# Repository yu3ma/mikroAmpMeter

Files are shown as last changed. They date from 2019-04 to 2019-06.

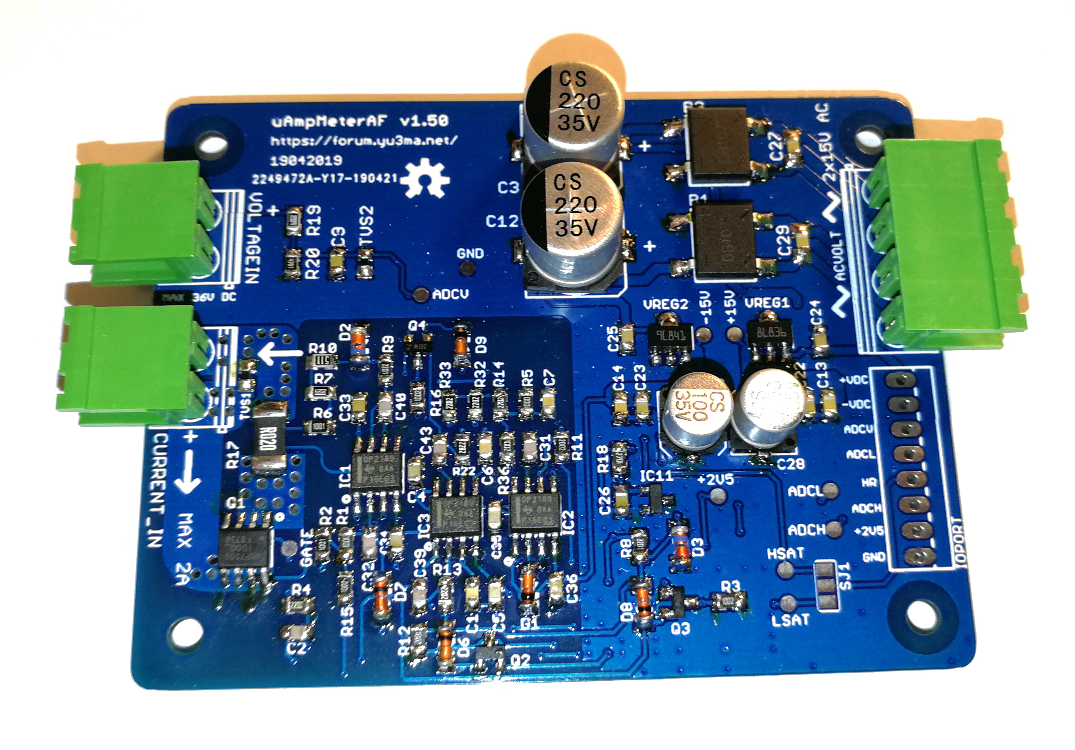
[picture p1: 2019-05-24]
Photos/IMG_20190524_214619.jpg

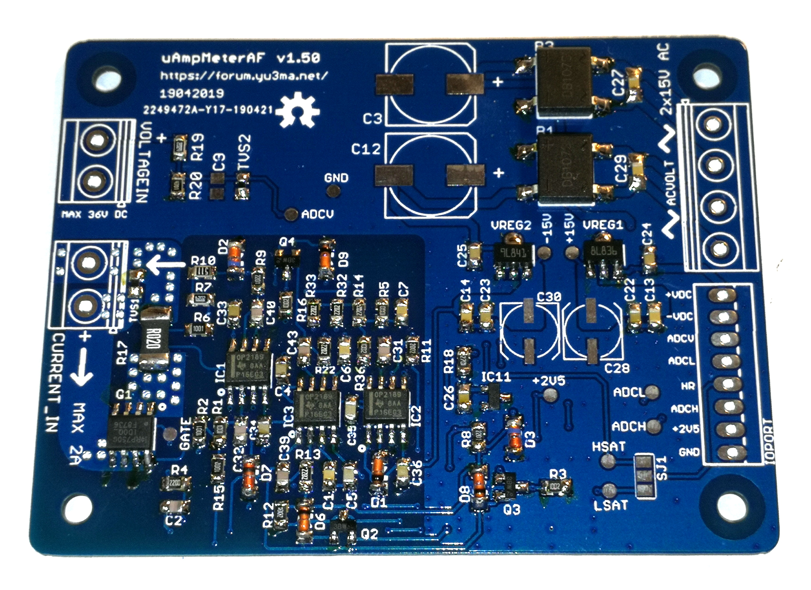
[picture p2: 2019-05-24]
Photos/IMG_20190524_213330.jpg

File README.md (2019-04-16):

# mikroAmpMeter
Universal Current measurement device for Low power devices

Major setup in analog electronic is made by @Macola and @Dragan100 on forum:
https://forum.yu3ma.net/thread-2158-post-94918.html#pid94918

Main purpose of this analog electronics is how to measure small current signal down to uA (microAmp) and 
auto range after 5mA to biger range which support up to 2A, without interuption of current flow. This analog part 
is connected on MCU Unit. 
MCU Unit is designed for acumulating measures of current for long period of dynamic current consumption of
low-power devices like GSM enabled devices, LoRa and NB-IoT devices.

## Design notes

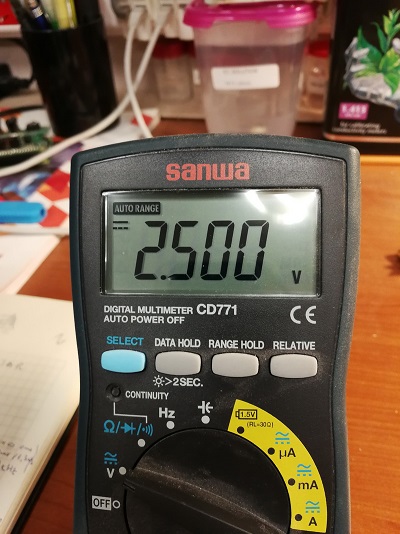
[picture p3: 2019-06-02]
Photos/IMG_20190525_111225_resize.jpg

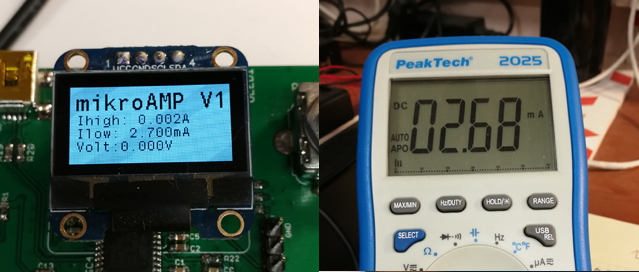
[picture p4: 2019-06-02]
Photos/SideBySide.jpg

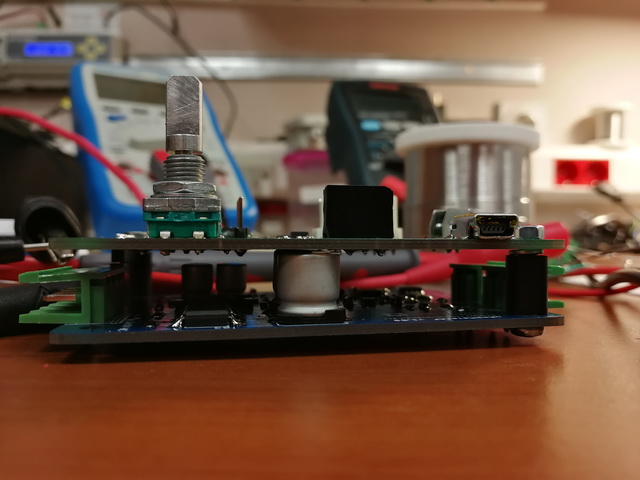
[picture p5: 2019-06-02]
Photos/IMG_20190525_134402_Resize.jpg

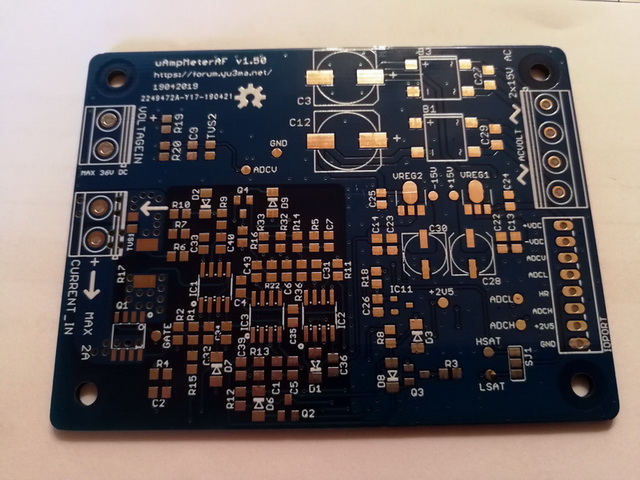
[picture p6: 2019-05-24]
Photos/IMG_20190510_172349_Resize.jpg

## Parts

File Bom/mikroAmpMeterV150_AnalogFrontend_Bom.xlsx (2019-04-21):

Partlist exported from Project mikroAmpMeterV150_AnalogFrontend.sch at 20-Apr-19 16:33:29 |  |  |  |  | Kompleta za izradu | 6 | Suma za 6 kompleta [EUR] | 109.44177 | Cene su bez PDV-a
Qty | Value | Device | Package | Parts | Description | Dobavljač | Oznaka | Jed Cena [EUR] | Ukupno Cena [EUR]
1 | 100R | R-EU_R0805 | R0805 | R5 | RESISTOR, European symbol | Comet | R0805 100R 1% (https://store.comet.rs/Catalogue/Product/3510/) | 0.01 | 0.01
12 | 100n | C-EUC0805 | C0805 | C4, C5, C22, C23, C33, C34, C35, C36, C9, C24, C25, C26 | CAPACITOR, European symbol | Comet | C0805 100nF 50V X7R YAG (https://store.comet.rs/Catalogue/Product/16789/) | 0.01 | 0.12
2 | 10K0 0.1% | R-EU_R0805 | R0805 | R15, R12 | RESISTOR, European symbol | Farnell | 1575900 | 0.224825 | 0.44965
3 | 10k | R-EU_R0805 | R0805 | R3, R16, R36 | RESISTOR, European symbol | Comet | R0805 10K 1% (https://store.comet.rs/Catalogue/Product/29760/) | 0.01 | 0.03
2 | 10n | C-EUC0805 | C0805 | C13, C14 | CAPACITOR, European symbol | Comet | C0805 10nF 50V X7R SAMSUNG (https://store.comet.rs/Catalogue/Product/23248/) | 0.015 | 0.03
2 | 10nF | C-EUC1206 | C1206 | C27, C29 | CAPACITOR, European symbol | Comet | C0805 10nF 50V X7R SAMSUNG (https://store.comet.rs/Catalogue/Product/23248/) | 0.015 | 0.03
4 | 1N4148 | DIODE-SOD80C | SOD80C | D1, D6, D8, D9 | DIODE | Comet | LL4148 SMD SM (https://store.comet.rs/Catalogue/Product/45237/) | 0.01 | 0.04
1 | 1k | R-EU_R0805 | R0805 | R1 | RESISTOR, European symbol | Comet | R0805 1.0K 1% YAG/ASJ (https://store.comet.rs/Catalogue/Product/24897/) | 0.01 | 0.01
2 | 1k0 0.1% | R-EU_R0805 | R0805 | R2, R6 | RESISTOR, European symbol | Farnell | 1575792 | 0.224825 | 0.44965
3 | 1n | C-EUC0805 | C0805 | C1, C6, C7 | CAPACITOR, European symbol | Comet | C0805 1.0nF 50V X7R SAMSUNG (https://store.comet.rs/Catalogue/Product/23211/) | 0.01 | 0.03
1 | 20k 0.1% | R-EU_R0805 | R0805 | R11 | RESISTOR, European symbol | Farnell | 1575937 | 0.224825 | 0.224825
1 | 220R | R-EU_R0805 | R0805 | R4 | RESISTOR, European symbol | Comet | 0805 220R 1% (https://store.comet.rs/Catalogue/Product/3516/) | 0.01 | 0.01
2 | 220uF/35V | CPOL-US153CLV-1014 | 153CLV-1014 | C3, C12 | POLARIZED CAPACITOR, American symbol | Comet | CE 220uF 35V SMD Fujicon (https://store.comet.rs/Catalogue/Product/36242/) | 0.12 | 0.24
4 | 22k | R-EU_R0805 | R0805 | R13, R22, R32, R33 | RESISTOR, European symbol | Comet | R0805 22K 1% (https://store.comet.rs/Catalogue/Product/4213/) | 0.01 | 0.04
1 | 27k | R-EU_R0805 | R0805 | R14 | RESISTOR, European symbol | Comet | R0805 27K 1% (https://store.comet.rs/Catalogue/Product/3553/) | 0.01 | 0.01
2 | 2k2 | R-EU_R0805 | R0805 | R8, R9 | RESISTOR, European symbol | Comet | R0805 2.2K 1% (https://store.comet.rs/Catalogue/Product/3534/) | 0.01 | 0.02
1 | 2k7 | R-EU_R0805 | R0805 | R18 | RESISTOR, European symbol | Comet | R0805 2.7K 1% (https://store.comet.rs/Catalogue/Product/29757/) | 0.01 | 0.01
6 | 33p | C-EUC0805 | C0805 | C2, C31, C32, C39, C40, C43 | CAPACITOR, European symbol | Comet | C0805 33pF 50V C0G SAMSUNG (https://store.comet.rs/Catalogue/Product/23086/) | 0.01 | 0.06
1 | 4k7 0.1% | R-EU_R0805 | R0805 | R20 | RESISTOR, European symbol | Farnell | 2337870 | 0.309465 | 0.309465
1 | 510R0 0.1% | R-EU_R0805 | R0805 | R10 | RESISTOR, European symbol | Farnell | 1653311 | 0.2922725 | 0.2922725
2 | 62k0 0.1% | R-EU_R0805 | R0805 | R7, R19 | RESISTOR, European symbol | Mouser | ERJ-PB6B6202V | 0.2652 | 0.5304
3 | BC856ASMD | BC856ASMD | SOT23-BEC | Q2, Q3, Q4 | PNP Transistror | Comet | BC856B SMD (https://store.comet.rs/Catalogue/Product/22306/) | 0.02 | 0.06
1 | BZX84C8V2L | ZENER-DIODESOD80C | SOD80C | D7 | Z-Diode | Comet | BZV55C8V2 (https://store.comet.rs/Catalogue/Product/25753/) | 0.01 | 0.01
2 | CE 100uF 35V SMD | CPOL-EUUD-6,3X7,7 | UD-6,3X7,7_NICHICON | C28, C30 | POLARIZED CAPACITOR, European symbol | Comet | CE 100uF 35V SMD Fujicon (https://store.comet.rs/Catalogue/Product/29570/) | 0.04 | 0.08
2 | CG0603MLC-05E | TVS | R0805 | TVS1, TVS2 | TVS Varistor, 8 V, 5 V, ChipGuard MLC Series | Farnell | 1838966 | 0.1811825 | 0.362365
1 | 0.02R 1% 2W | R-EU_R2512 | R2512 | R17 | RESISTOR, European symbol | Comet | R2512 0.02R 1% 2W (https://store.comet.rs/en/Catalogue/Product/35370/) | 0.6916675 | 0.6916675 | Alternativa Farnell: CRA2512-FZ-R020ELF 1435948
2 | DB104S | DBLS204G | DBS | B1, B3 | Single Phase 1.0 AMP Glass Passivated Bridge Rectifier | Comet | DB107S SMD (https://store.comet.rs/Catalogue/Product/16915/) | 0.07 | 0.14
1 | IRF8736 | IRF8736 | SO-8 | Q1 | 30V N-Channel PowerTrench TM MOSFET | Comet | IRF8736 (https://store.comet.rs/Catalogue/Product/44982/) | 0.03 | 0.03
1 | L78L15ACUTR | 78L05F | SOT89 | VREG1 | POSITIVE-VOLTAGE REGULATORS | Farnell | 2849738 | 0.12 | 0.12
1 | L79L15ACUTR | L79L15ACUTR | SOT89 | VREG2 | NEGATIVE-VOLTAGE REGULATORS | Farnell | 2849762 | 0.4 | 0.4
1 | LM4040CYM3-2.5-TR | LM4041A12DBZ | DBZ_R-PDSO-G3 | IC11 | PRECISION MICROPOWER SHUNT VOLTAGE REFERENCE | Comet | LM4040CYM3-2.5-TR (https://store.comet.rs/Catalogue/Product/99257/) | 0.3 | 0.3
2 | MKDSN1,5/2-5,08 | MKDSN1,5/2-5,08 | MKDSN1,5/2-5,08 | CURRENT_IN, VOLTAGEIN | MKDSN 1,5/ 2-5,08 Printklemme | Comet | HD-515R 2P (https://store.comet.rs/Catalogue/Product/2629/) | 0.4 | 0.8
1 | MKDSN1,5/4-5,08 | MKDSN1,5/4-5,08 | MKDSN1,5/4-5,08 | ACVOLT | MKDSN 1,5/ 4-5,08 Printklemme | Comet | HD-515R 4P (https://store.comet.rs/Catalogue/Product/2631/) | 0.8 | 0.8
3 | OPA2189IDR | OPA2189IDR | SO08@1 | IC1, IC2, IC3 | High Precision, Low Noise OPERATIONAL AMPLIFIERS | Mouser | 595-OPA2189IDR | 3.66 | 10.98
2 | TMMBAT48FILM | Shotky DIODE | SOD80C | D2, D3 | Shotky Diode | Comet | TMMBAT48 (https://store.comet.rs/Catalogue/Product/44949/) | 0.01 | 0.02
 |  |  |  |  |  |  |  |  | 0
1 | PCB | Dvoslojna plave boje | 61x81mm |  |  | JLCPCB |  | 0.5 | 0.5
 |  |  |  |  |  |  |  | SUMARNO za 1 kom | 18.240295

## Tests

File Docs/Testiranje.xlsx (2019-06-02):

Imer [mA] | ADCL [V] | ADCH [V] | HSAT [V] | LSAT [V]
1.92 | 1.261 |  | 3.167 | 3.167 | otpornik
2.51 | 0.907 |  | 3.167 | 3.167 | otpornik
318 | 2.5 | 0.403 | 3.167 | 0.05 | motor

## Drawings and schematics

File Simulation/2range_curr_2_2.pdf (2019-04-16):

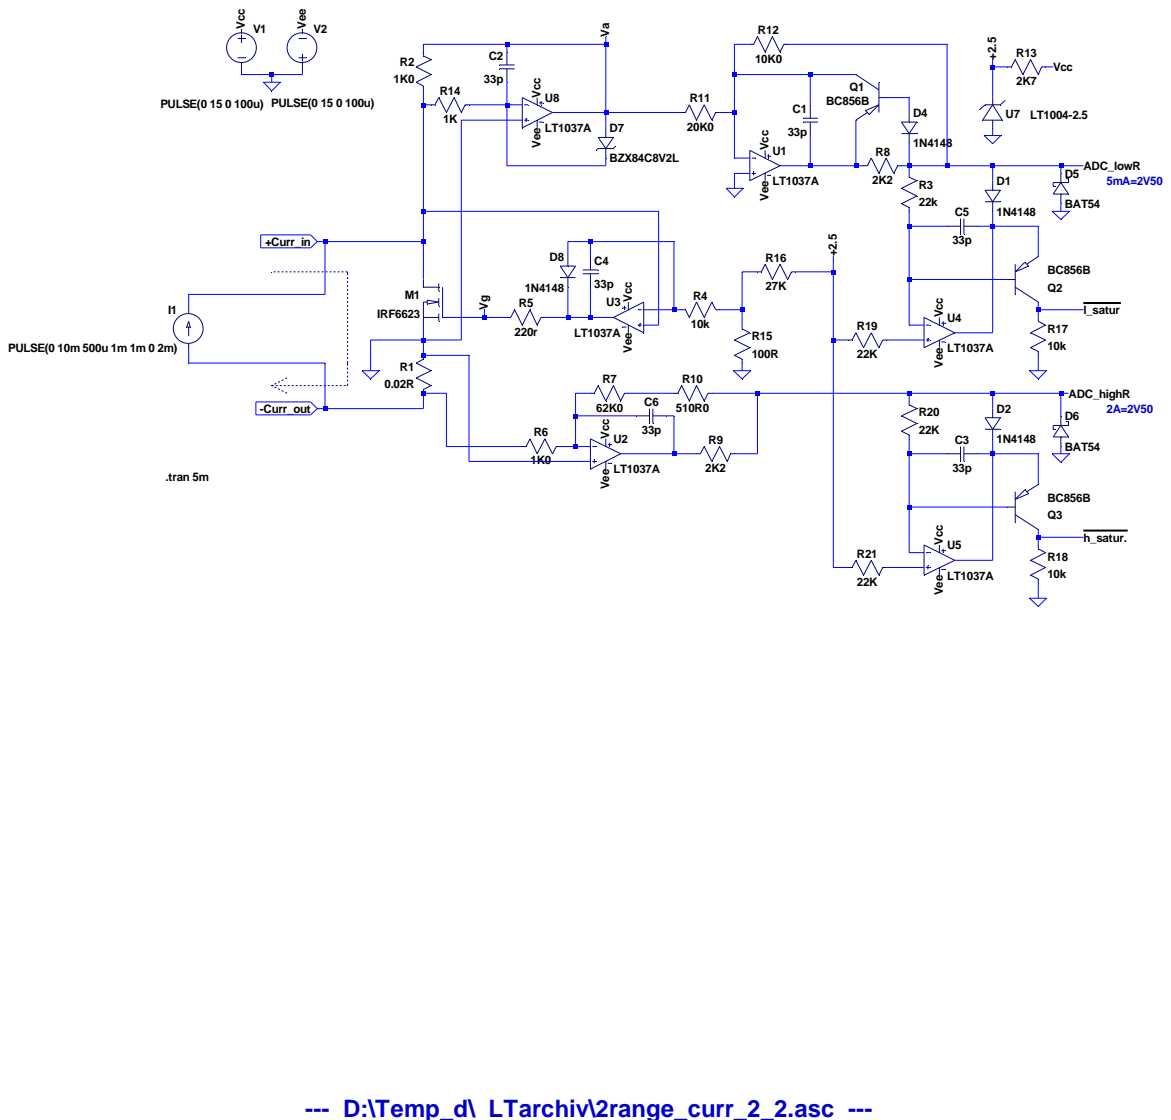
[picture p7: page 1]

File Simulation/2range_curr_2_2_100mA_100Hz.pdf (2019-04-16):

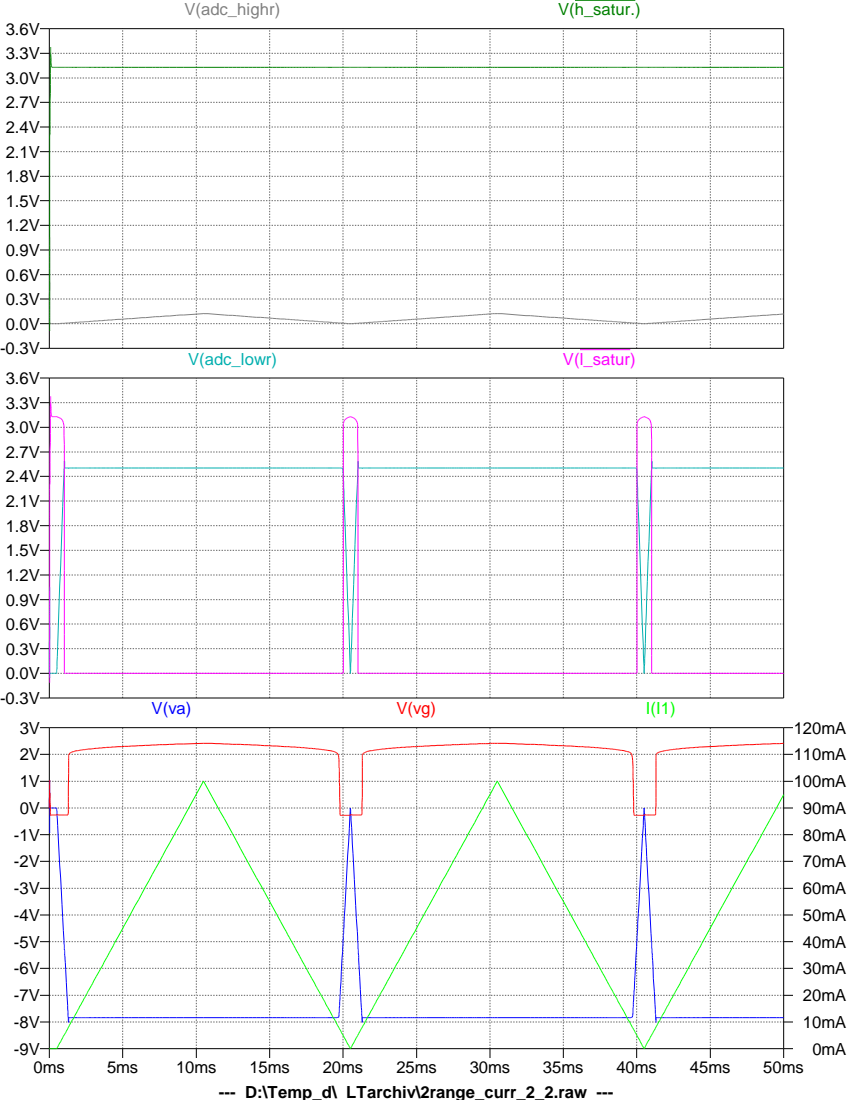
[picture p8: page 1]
V(adc_lowr); V(l_satur); V(adc_highr); V(h_satur.); --- D:\Temp_d\ LTarchiv\2range_curr_2_2.raw ---

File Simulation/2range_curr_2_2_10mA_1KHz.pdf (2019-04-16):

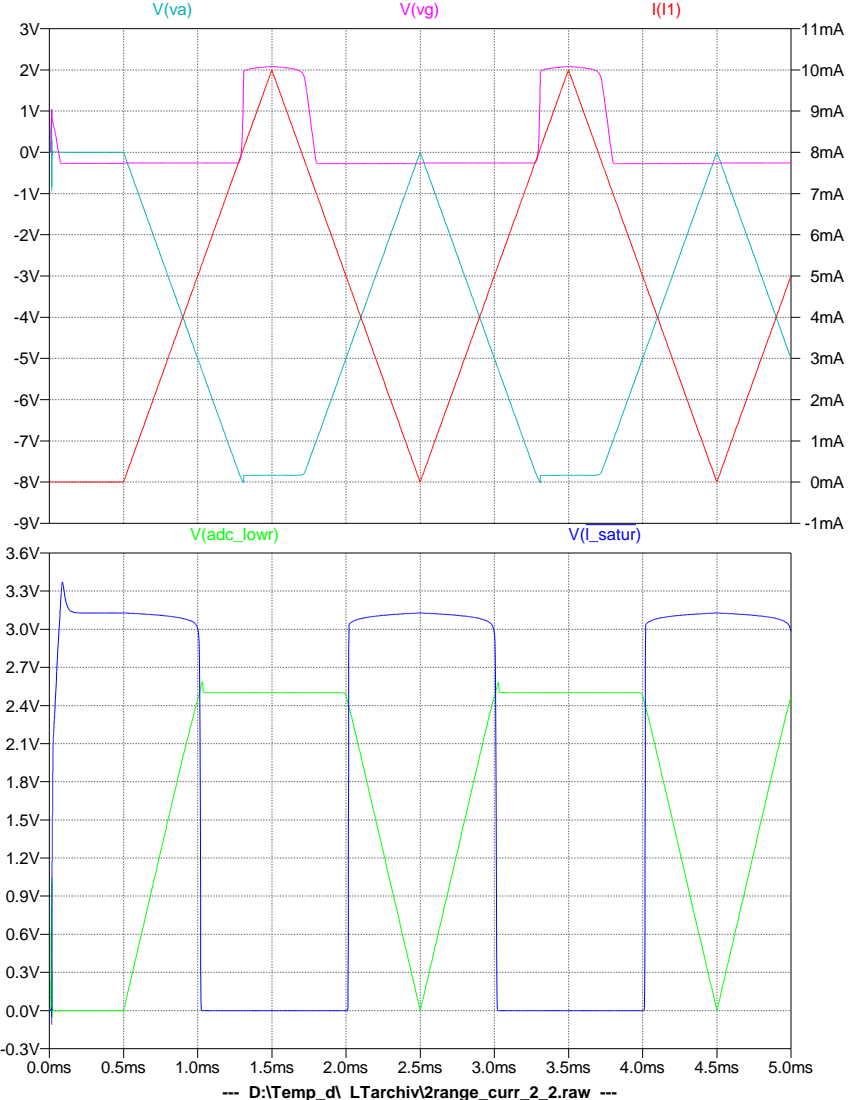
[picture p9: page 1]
V(adc_lowr); V(l_satur); --- D:\Temp_d\ LTarchiv\2range_curr_2_2.raw ---

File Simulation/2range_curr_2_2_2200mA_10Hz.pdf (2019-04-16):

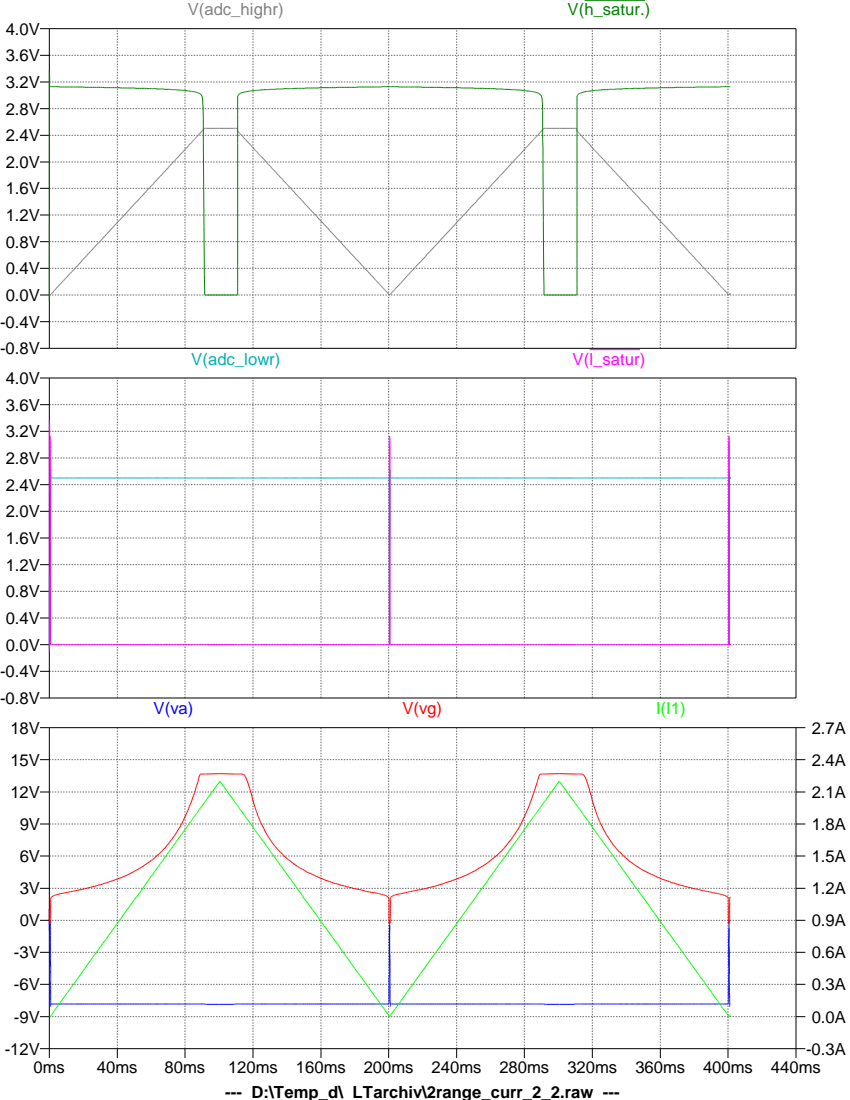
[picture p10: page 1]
V(adc_lowr); V(l_satur); V(adc_highr); V(h_satur.); --- D:\Temp_d\ LTarchiv\2range_curr_2_2.raw ---

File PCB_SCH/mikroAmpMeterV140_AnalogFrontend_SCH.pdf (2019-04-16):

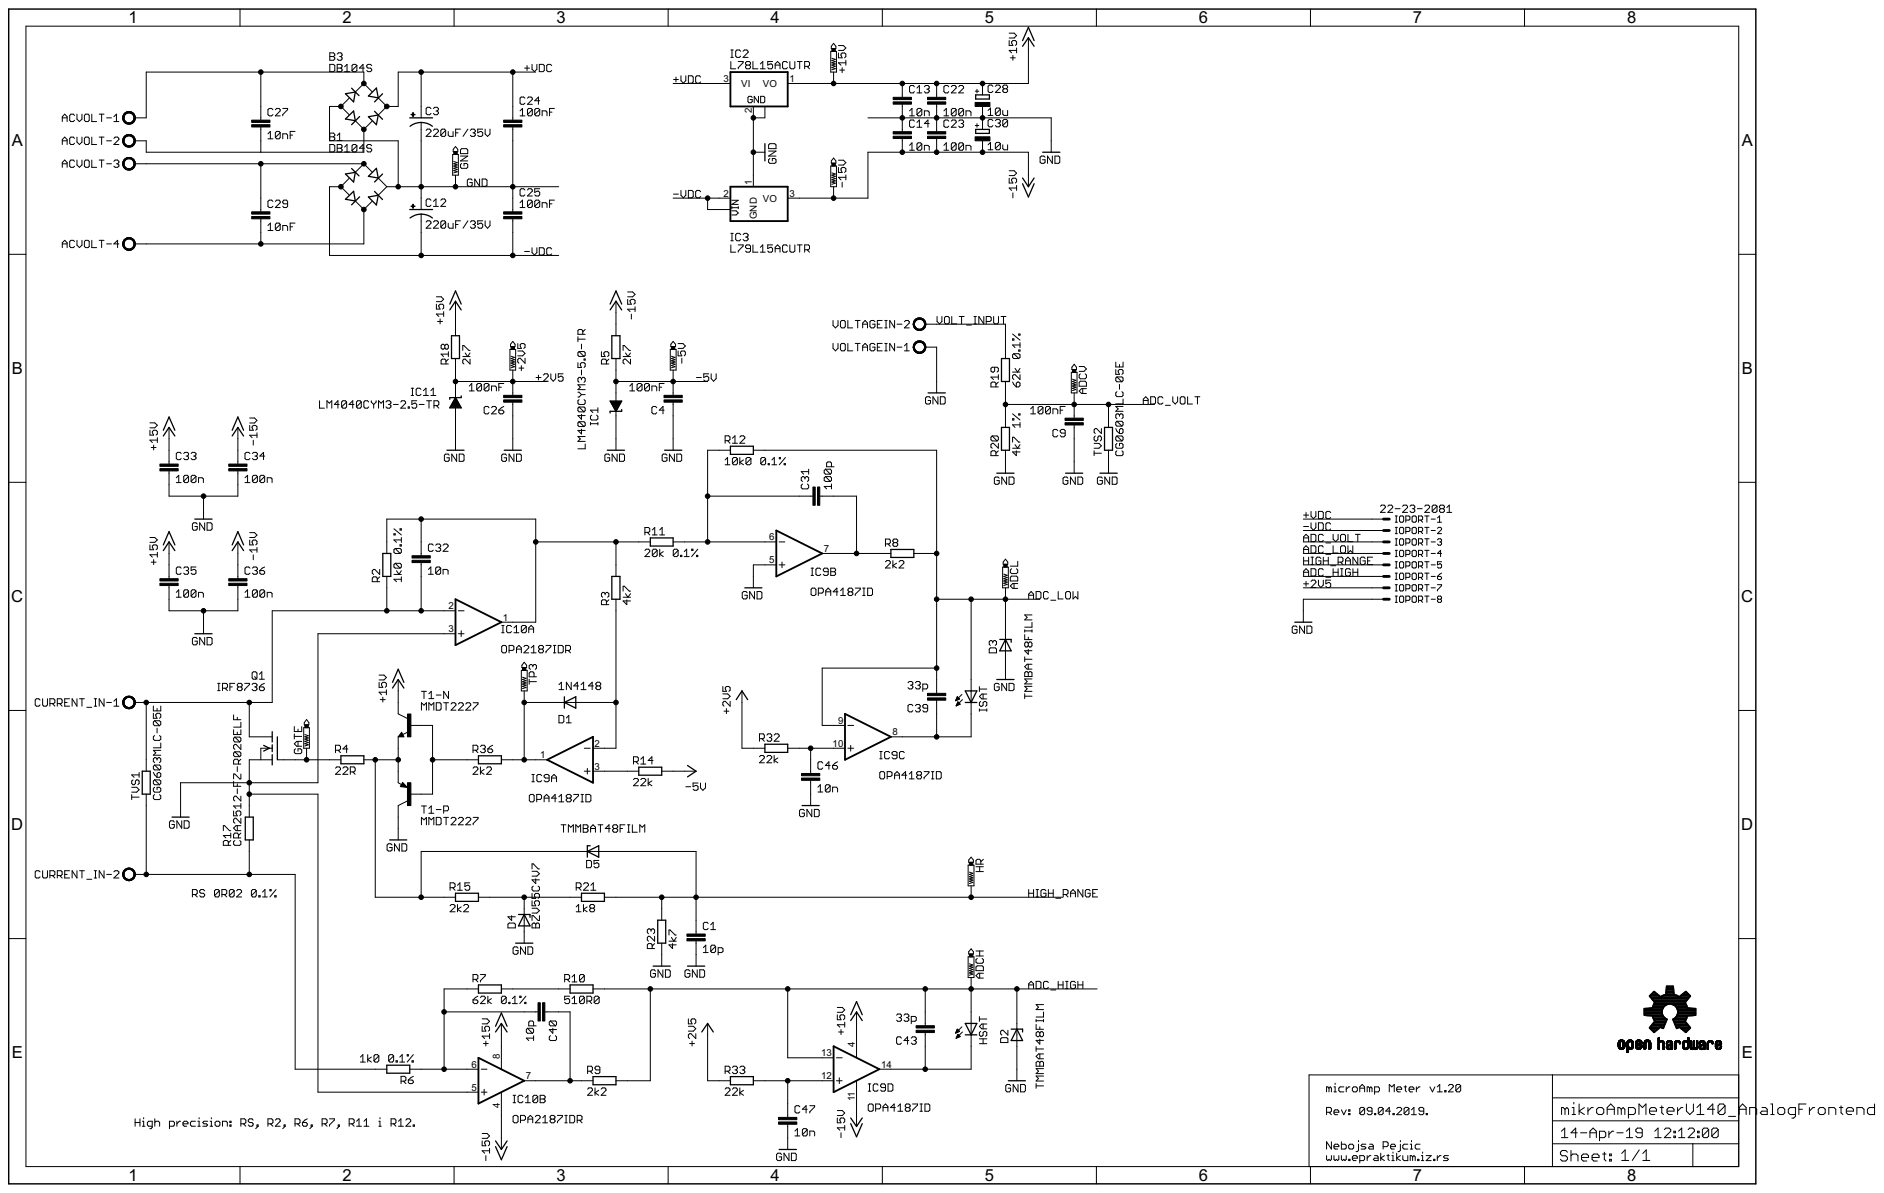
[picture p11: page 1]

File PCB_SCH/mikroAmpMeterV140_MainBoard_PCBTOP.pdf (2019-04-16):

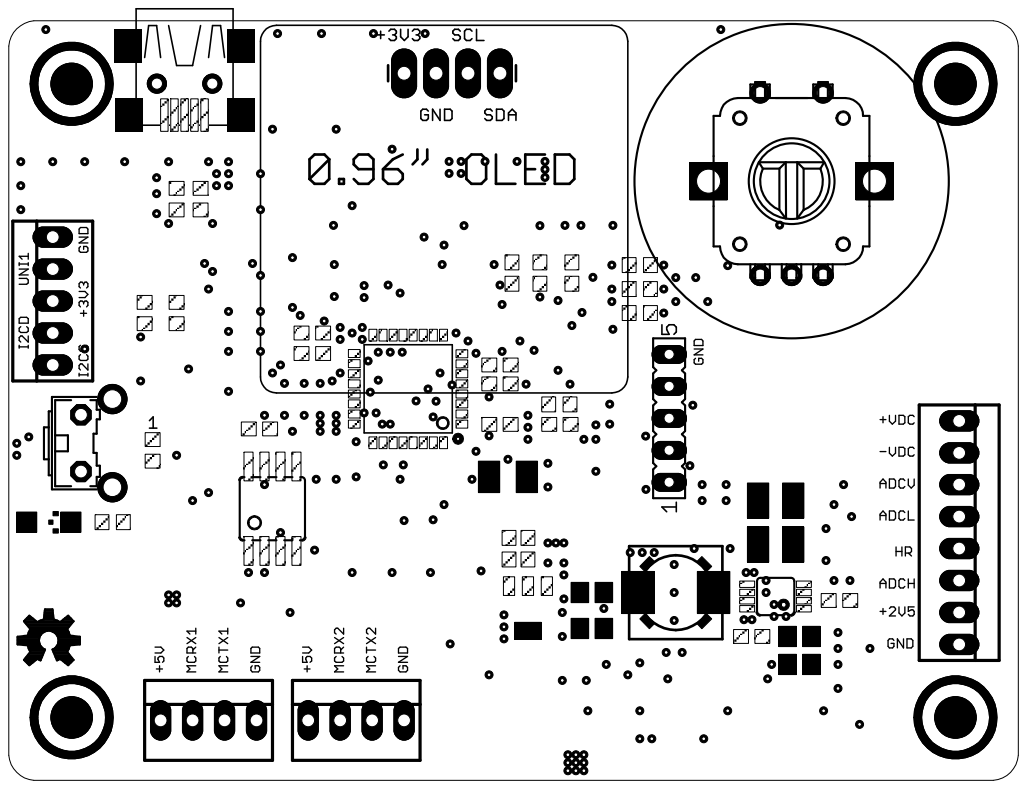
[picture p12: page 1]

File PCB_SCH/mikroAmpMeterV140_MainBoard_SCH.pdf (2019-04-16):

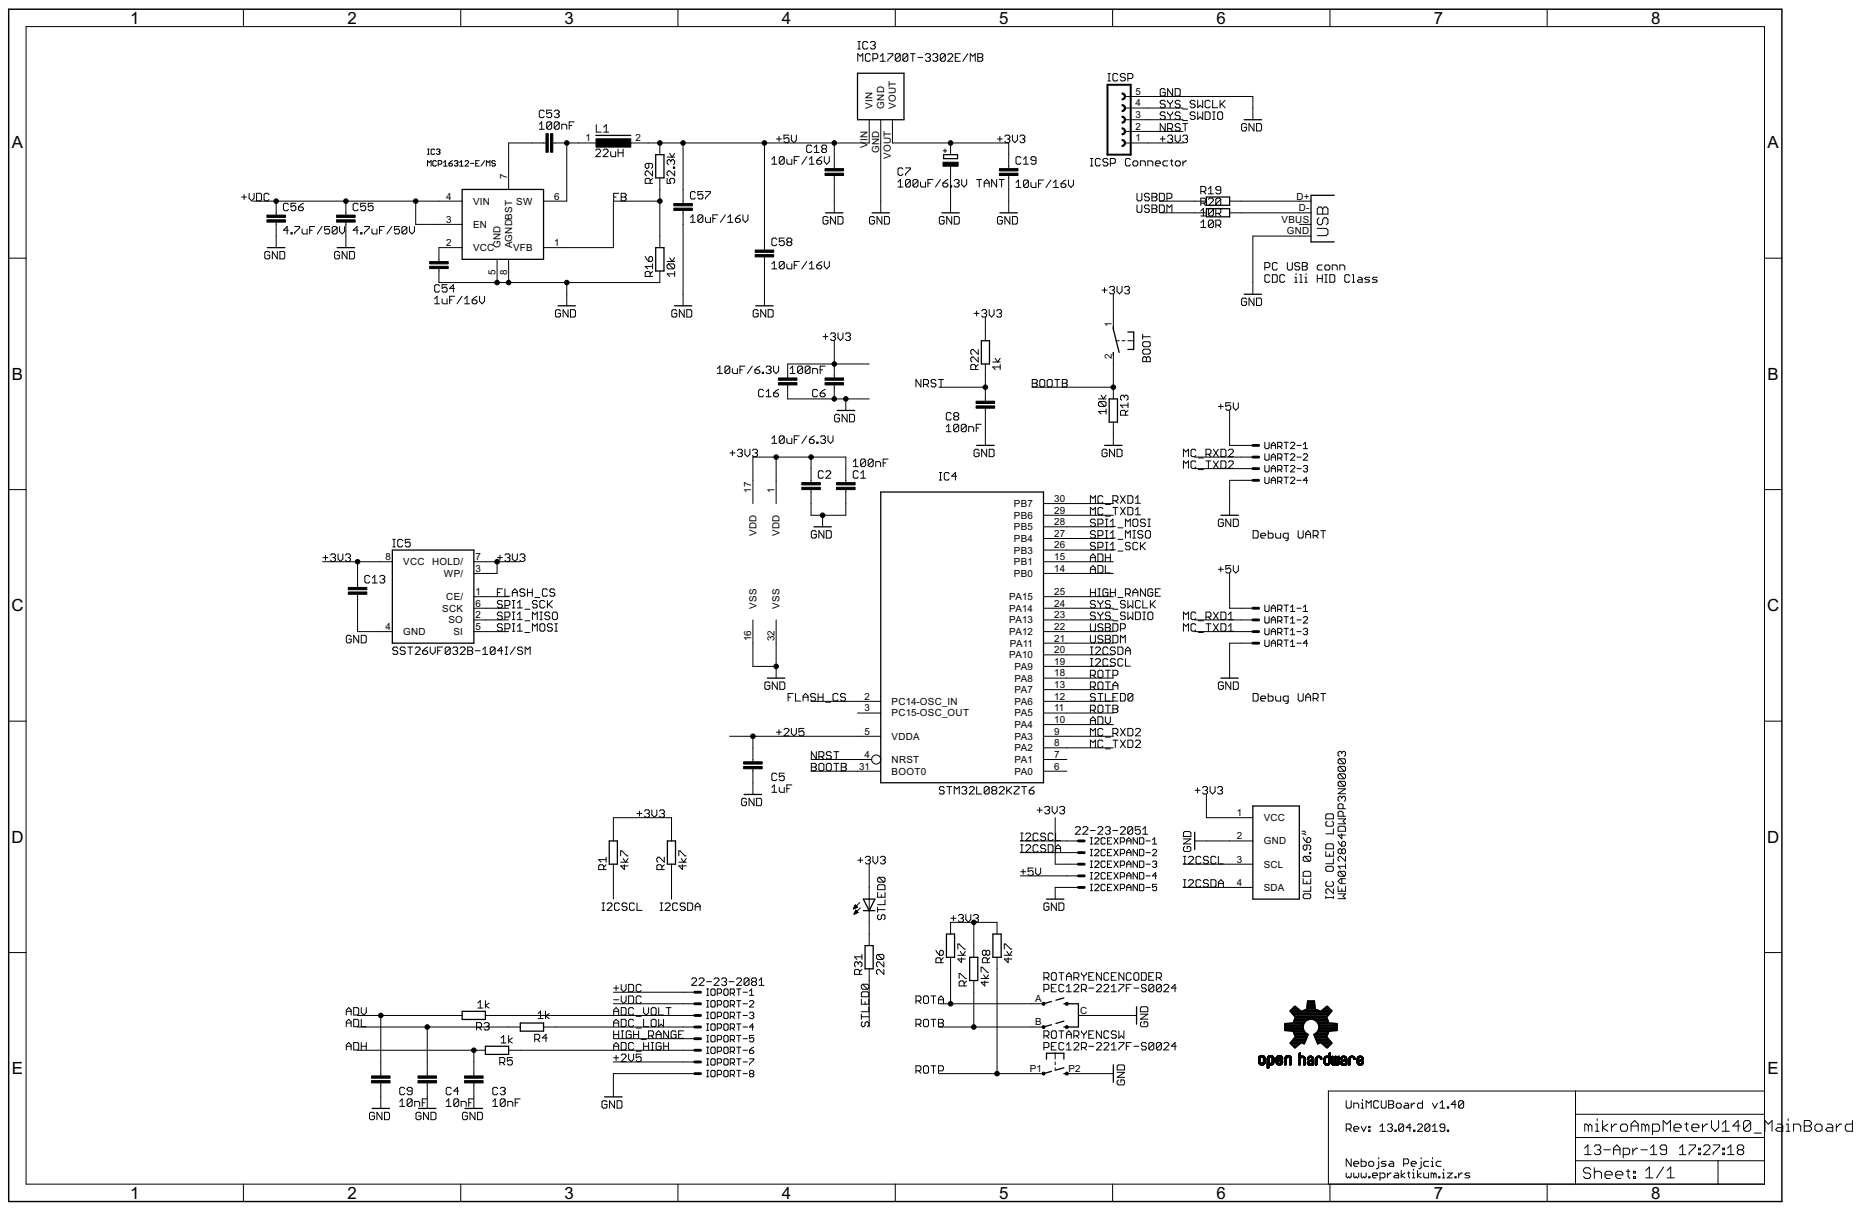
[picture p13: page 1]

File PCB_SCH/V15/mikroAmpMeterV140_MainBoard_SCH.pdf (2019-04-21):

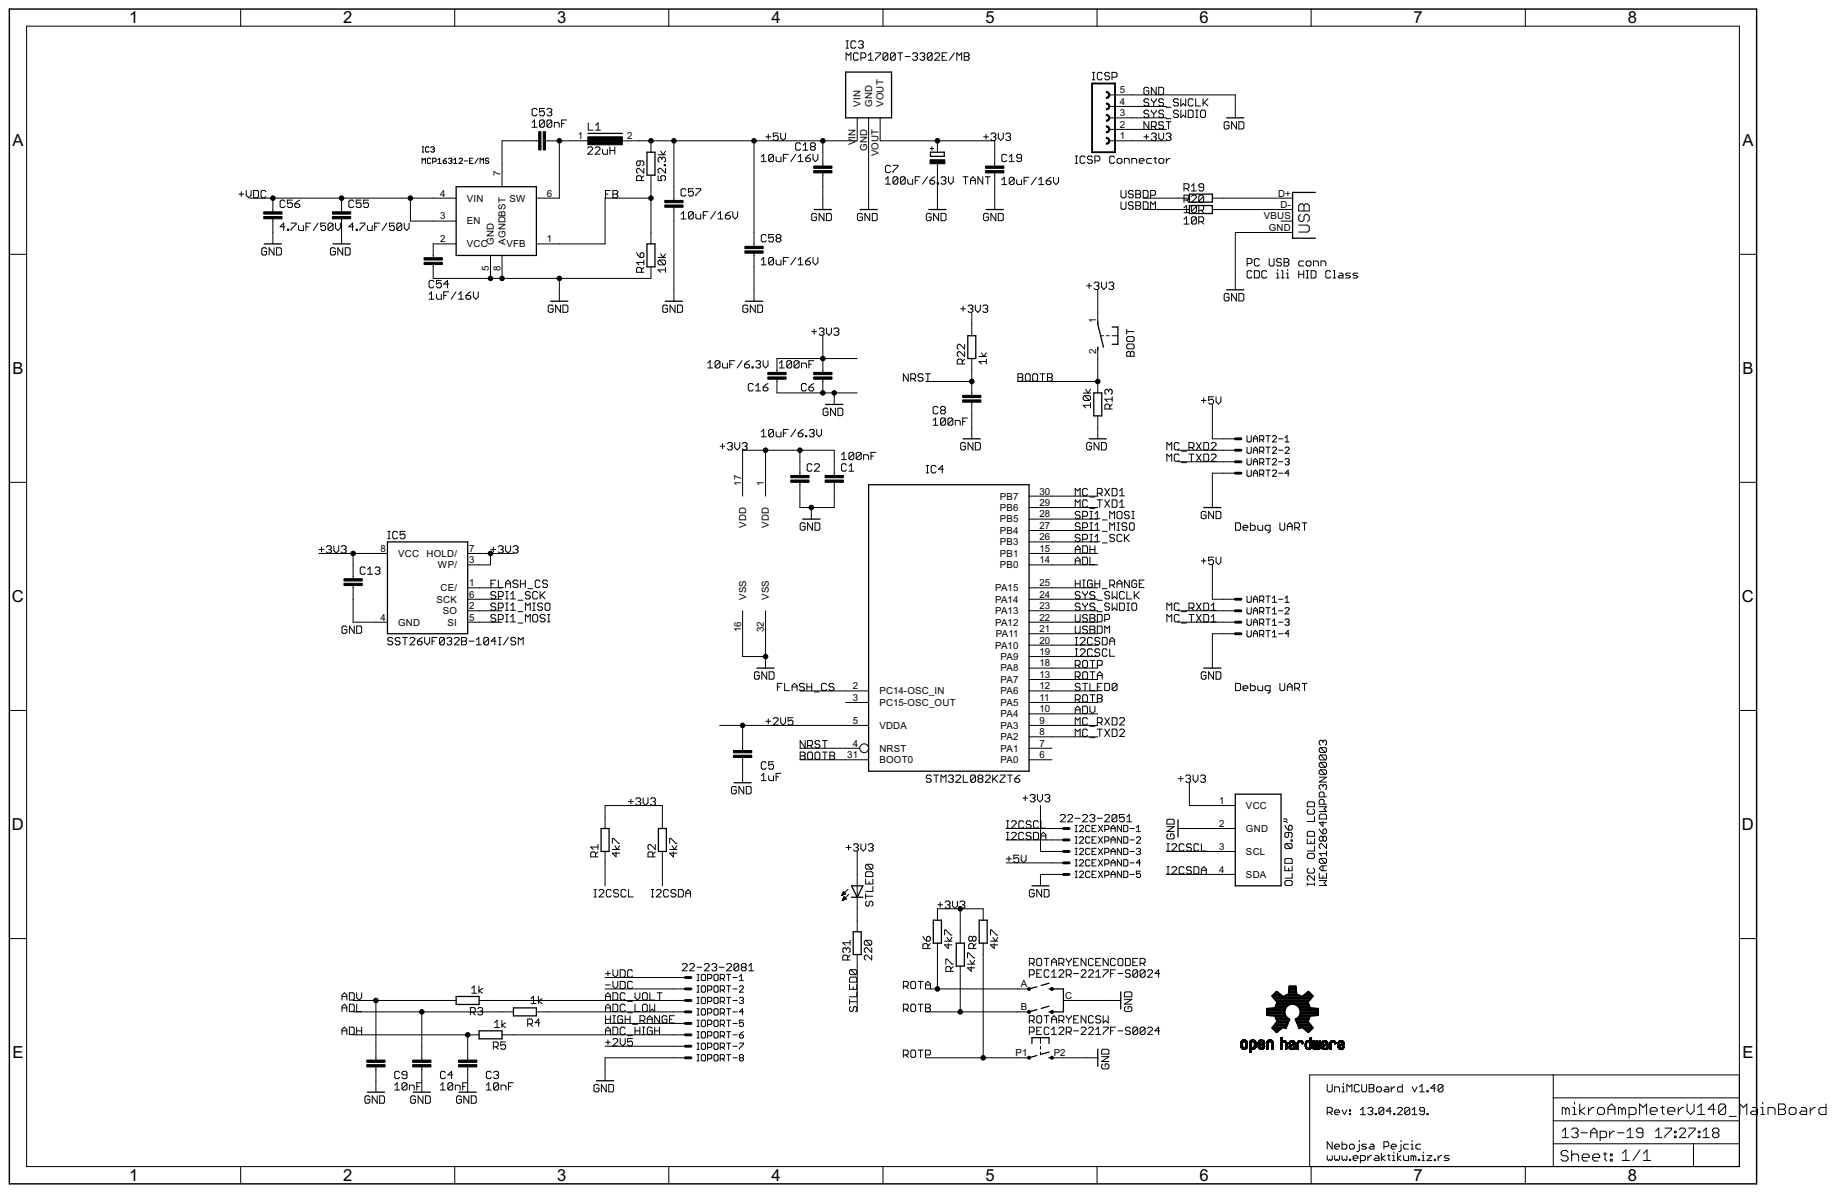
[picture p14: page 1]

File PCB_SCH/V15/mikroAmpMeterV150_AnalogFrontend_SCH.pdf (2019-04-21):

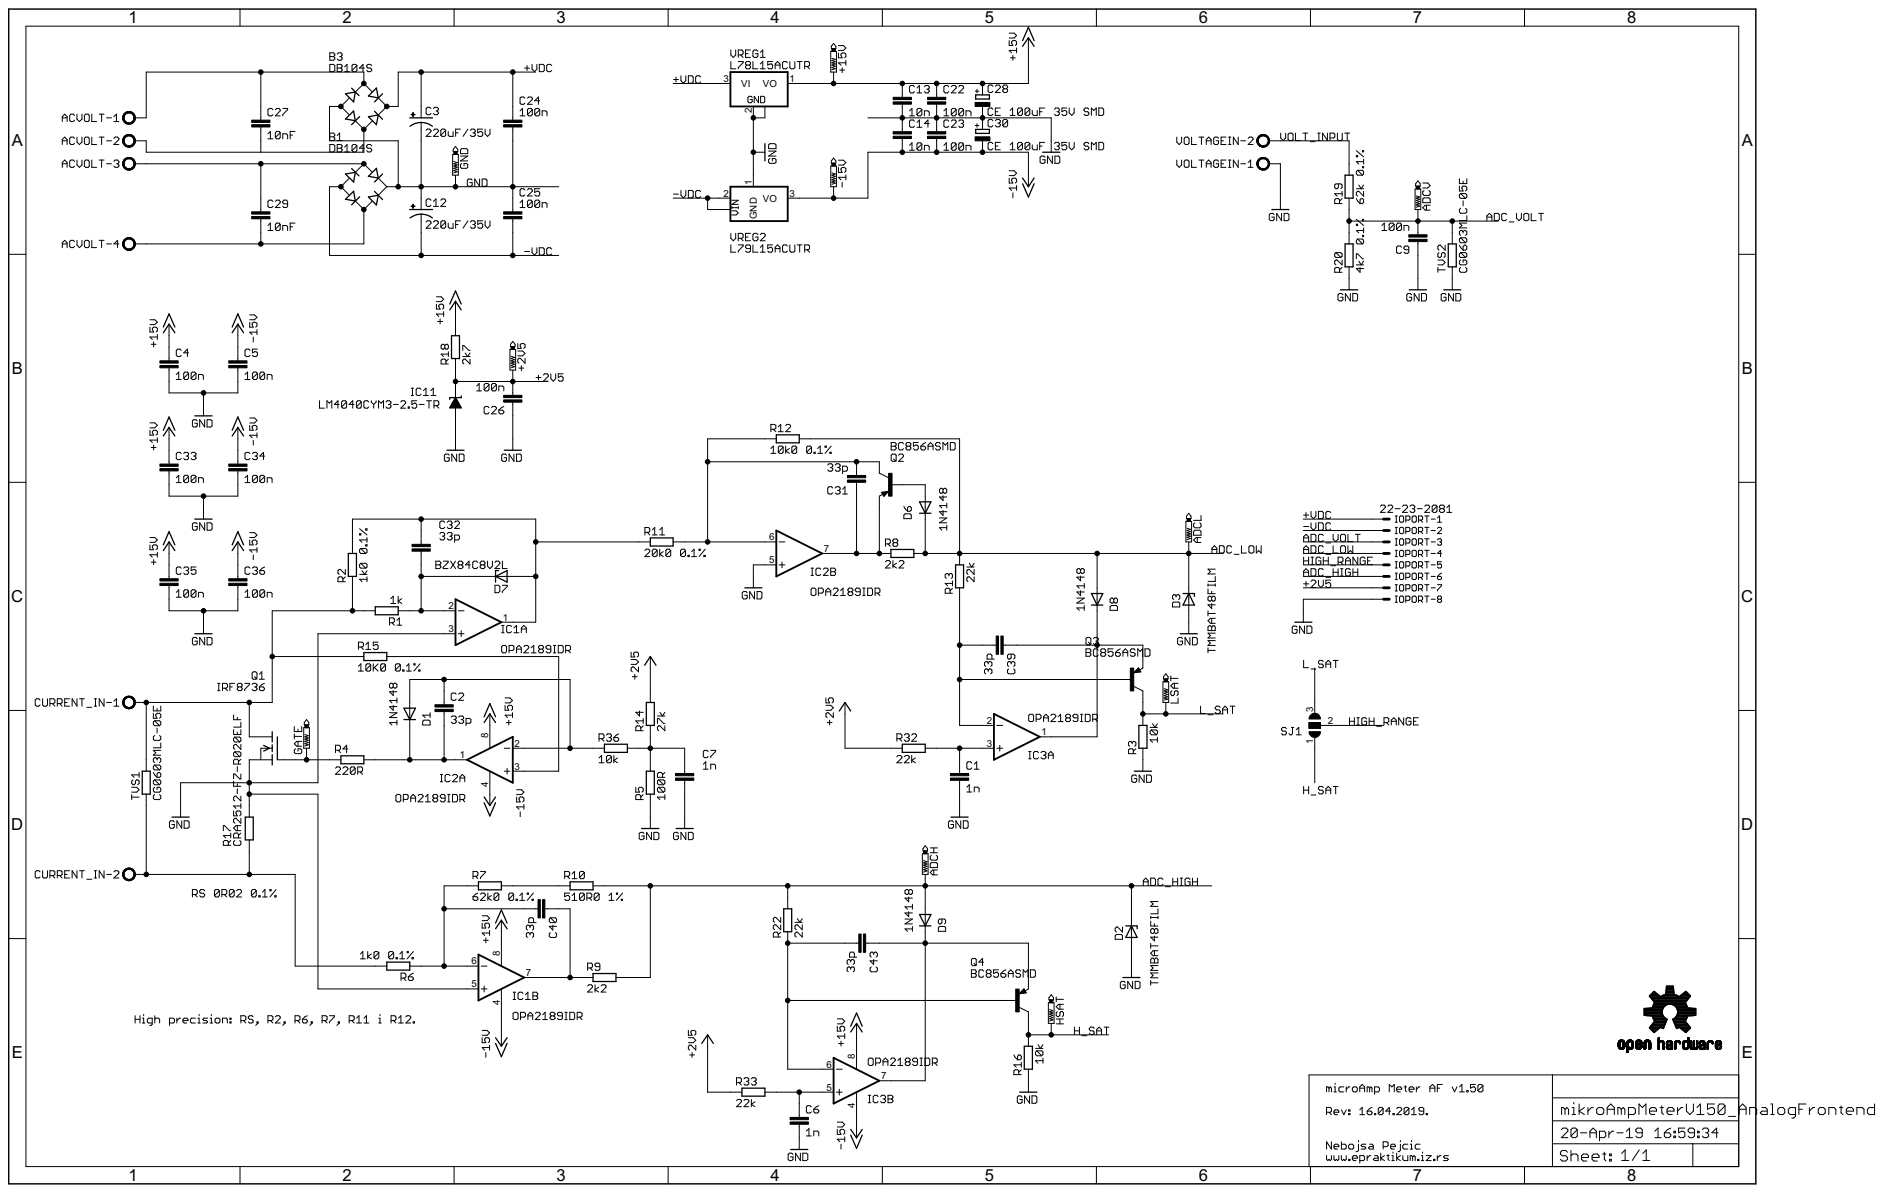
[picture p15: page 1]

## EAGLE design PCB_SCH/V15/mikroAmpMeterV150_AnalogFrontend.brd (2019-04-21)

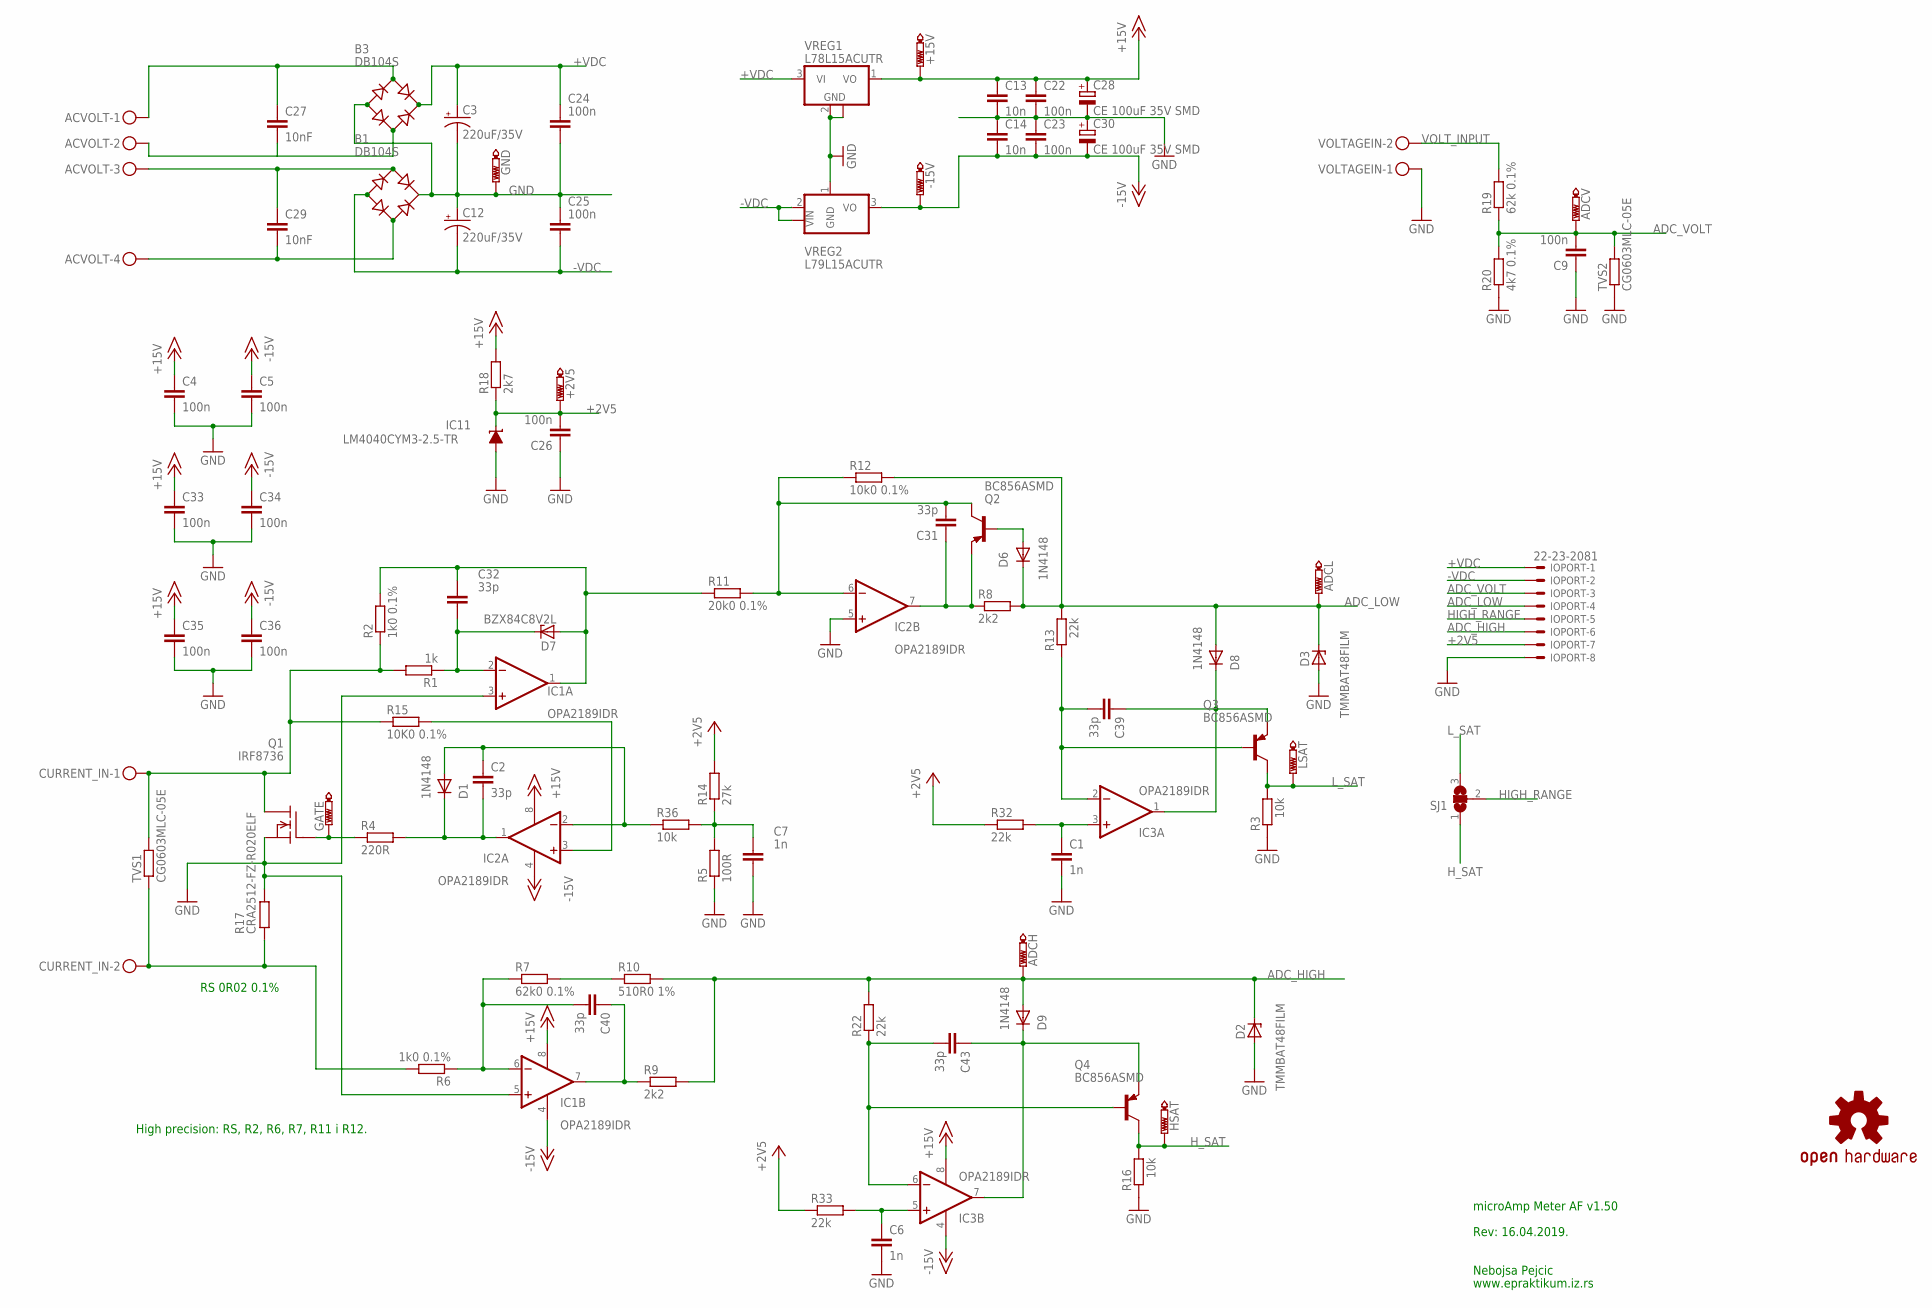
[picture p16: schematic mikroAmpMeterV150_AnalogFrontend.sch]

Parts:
+2V5, +15V: PTR1TP15R; TP15R
-15V: PTR1TP15R; TP15R
ACVOLT: MKDSN1,5/4-5,08
ADCH: PTR1TP15R; TP15R
ADCL: PTR1TP15R; TP15R
ADCV: PTR1TP15R; TP15R
B1, B3: DB104S; DBS
C1, C6, C7: 1n; C0805
C2, C31, C32, C39, C40, C43: 33p; C0805
C3, C12: 220uF/35V; 153CLV-1014
C4, C5, C9, C22, C23, C24, C25, C26, C33, C34, C35, C36: 100n; C0805
C13, C14: 10n; C0805
C27, C29: 10nF; C1206
C28, C30: CE 100uF 35V SMD; UD-6,3X7,7_NICHICON
CURRENT_IN: MKDSN1,5/2-5,08
D1, D6, D8, D9: 1N4148; SOD80C
D2, D3: TMMBAT48FILM; SOD80C
D7: BZX84C8V2L; SOD80C
GATE: PTR1TP15R; TP15R
GND: PTR1TP15R; TP15R
HSAT: PTR1TP15R; TP15R
IC1, IC2, IC3: OPA2189IDR; SO08@1
IC11: LM4040CYM3-2.5-TR; DBZ_R-PDSO-G3
IOPORT: 22-23-2081
LOGO1: OSHW-LOGOM; OSHW-LOGO-M
LSAT: PTR1TP15R; TP15R
Q1: IRF8736; SO-8
Q2, Q3, Q4: BC856ASMD; SOT23-BEC
R1: 1k; R0805
R2, R6: 1k0 0.1%; R0805
R3, R16, R36: 10k; R0805
R4: 220R; R0805
R5: 100R; R0805
R7: 62k0 0.1%; R0805
R8, R9: 2k2; R0805
R10: 510R0 1%; R0805
R11: 20k0 0.1%; R0805
R12: 10k0 0.1%; R0805
R13, R22, R32, R33: 22k; R0805
R14: 27k; R0805
R15: 10K0 0.1%; R0805
R17: CRA2512-FZ-R020ELF; R2512
R18: 2k7; R0805
R19: 62k 0.1%; R0805
R20: 4k7 0.1%; R0805
SJ1: SJ2W; SJ_2
TVS1, TVS2: CG0603MLC-05E; R0805
VOLTAGEIN: MKDSN1,5/2-5,08; MPN MKDSN 1,5/2-5.08
VREG1: L78L15ACUTR; SOT89
VREG2: L79L15ACUTR; SOT89

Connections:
+2V5: +2V5.TP, C26.2, IC11.1 (C), IOPORT.7, R14.2, R18.1, R32.1, R33.1
+15V: +15V.TP, C4.1, C13.1, C22.1, C28.+, C33.1, C35.1, IC1.8 (V+), IC2.8 (V+), IC3.8 (V+), R18.2, VREG1.1 (VO)
+VDC: B3.+, C3.+, C24.2, IOPORT.1, VREG1.3 (VI)
-15V: -15V.TP, C5.1, C14.2, C23.2, C30.-, C34.1, C36.1, IC1.4 (V-), IC2.4 (V-), IC3.4 (V-), VREG2.3 (VO)
-VDC: B1.-, C12.-, C25.1, IOPORT.2, VREG2.2 (VIN), VREG2.2@1 (VIN)
ADC_HIGH: ADCH.TP, D2.C, D9.A, IOPORT.6, R9.2, R10.2, R22.2
ADC_LOW: ADCL.TP, D3.C, D6.C, D8.A, IOPORT.4, R8.2, R12.2, R13.2
ADC_VOLT: ADCV.TP, C9.2, IOPORT.3, R19.1, R20.2, TVS2.2
CIN+: CURRENT_IN.1, Q1.5 (D), Q1.6 (D), Q1.7 (D), Q1.8 (D), R1.2, R2.1, R15.1, TVS1.2
CIN-: CURRENT_IN.2, R6.2, R17.1, TVS1.1
GND: B1.+, B3.-, C1.2, C3.-, C4.2, C5.2, C6.2, C7.2, C9.1, C12.+, C13.2, C14.1, C22.2, C23.1, C24.1, C25.2, C26.1, C28.-, C30.+, C33.2, C34.2, C35.2, C36.2, D2.A, D3.A, GND.TP, IC1.3 (+IN), IC1.5 (+IN), IC2.5 (+IN), IC11.2 (A), IOPORT.8, Q1.1 (S), Q1.2 (S), Q1.3 (S), R3.1, R5.1, R16.1, R17.2, R20.1, TVS2.1, VOLTAGEIN.1, VREG1.2 (GND), VREG1.2@1 (GND), VREG2.1 (GND)
HIGH_RANGE: IOPORT.5, SJ1.2
H_SAT: HSAT.TP, Q4.C, R16.2, SJ1.1
L_SAT: LSAT.TP, Q3.C, R3.2, SJ1.3
unnamed: C7.1, R5.2, R14.1, R36.2
unnamed: C32.2, D7.C, IC1.2 (-IN), R1.1
unnamed: C2.1, D1.A, IC2.2 (-IN), R36.1
unnamed: D6.A, Q2.B
unnamed: IC2.3 (+IN), R15.2
unnamed: C43.2, IC3.6 (-IN), Q4.B, R22.1
unnamed: C32.1, D7.A, IC1.1 (OUT), R2.2, R11.1
unnamed: C31.2, IC2.6 (-IN), Q2.C, R11.2, R12.1
unnamed: C31.1, IC2.7 (OUT), Q2.E, R8.1
unnamed: C39.2, IC3.2 (-IN), Q3.B, R13.1
unnamed: ACVOLT.1, B3.AC1, C27.2
unnamed: ACVOLT.2, B3.AC2, C27.1
unnamed: ACVOLT.3, B1.AC1, C29.2
unnamed: ACVOLT.4, B1.AC2, C29.1
unnamed: GATE.TP, Q1.4 (G), R4.1
unnamed: C2.2, D1.C, IC2.1 (OUT), R4.2
unnamed: C39.1, D8.C, IC3.1 (OUT), Q3.E
unnamed: C40.2, IC1.6 (-IN), R6.1, R7.1
unnamed: R7.2, R10.1
unnamed: C40.1, IC1.7 (OUT), R9.1
unnamed: C43.1, D9.C, IC3.7 (OUT), Q4.E
unnamed: C6.1, IC3.5 (+IN), R33.2
unnamed: C1.1, IC3.3 (+IN), R32.2
VOLT_INPUT: R19.2, VOLTAGEIN.2

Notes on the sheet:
microAmp Meter AF v1.50
Nebojsa Pejcic
Rev: 16.04.2019.
www.epraktikum.iz.rs
High precision: RS, R2, R6, R7, R11 i R12.
RS 0R02 0.1%

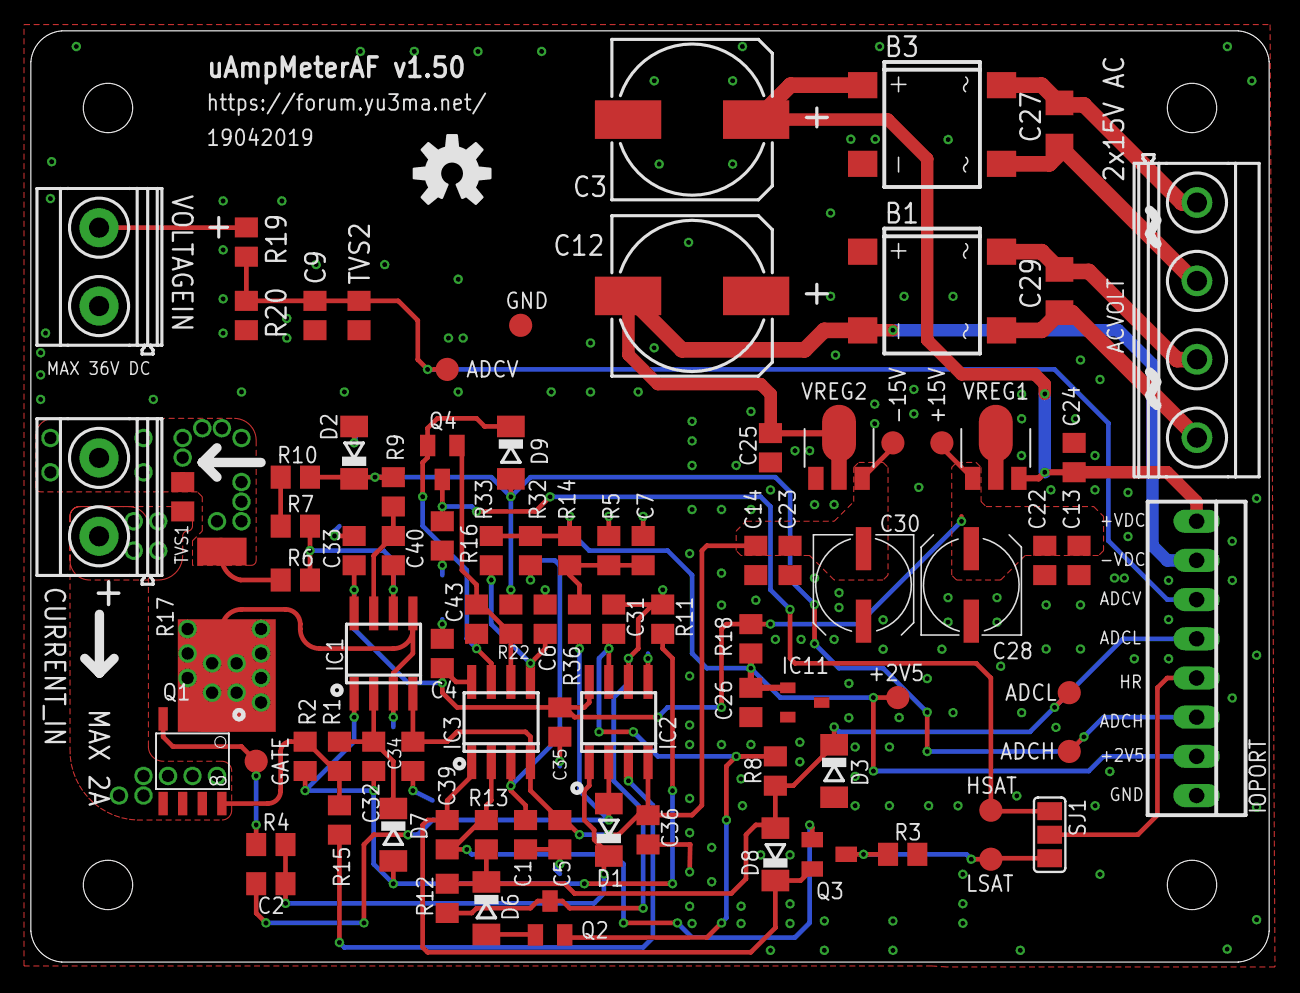
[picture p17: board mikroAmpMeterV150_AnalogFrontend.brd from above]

Board: 2 copper layers, 80.3 x 60.4 mm, 90 parts (0 on the bottom side), 38 nets.

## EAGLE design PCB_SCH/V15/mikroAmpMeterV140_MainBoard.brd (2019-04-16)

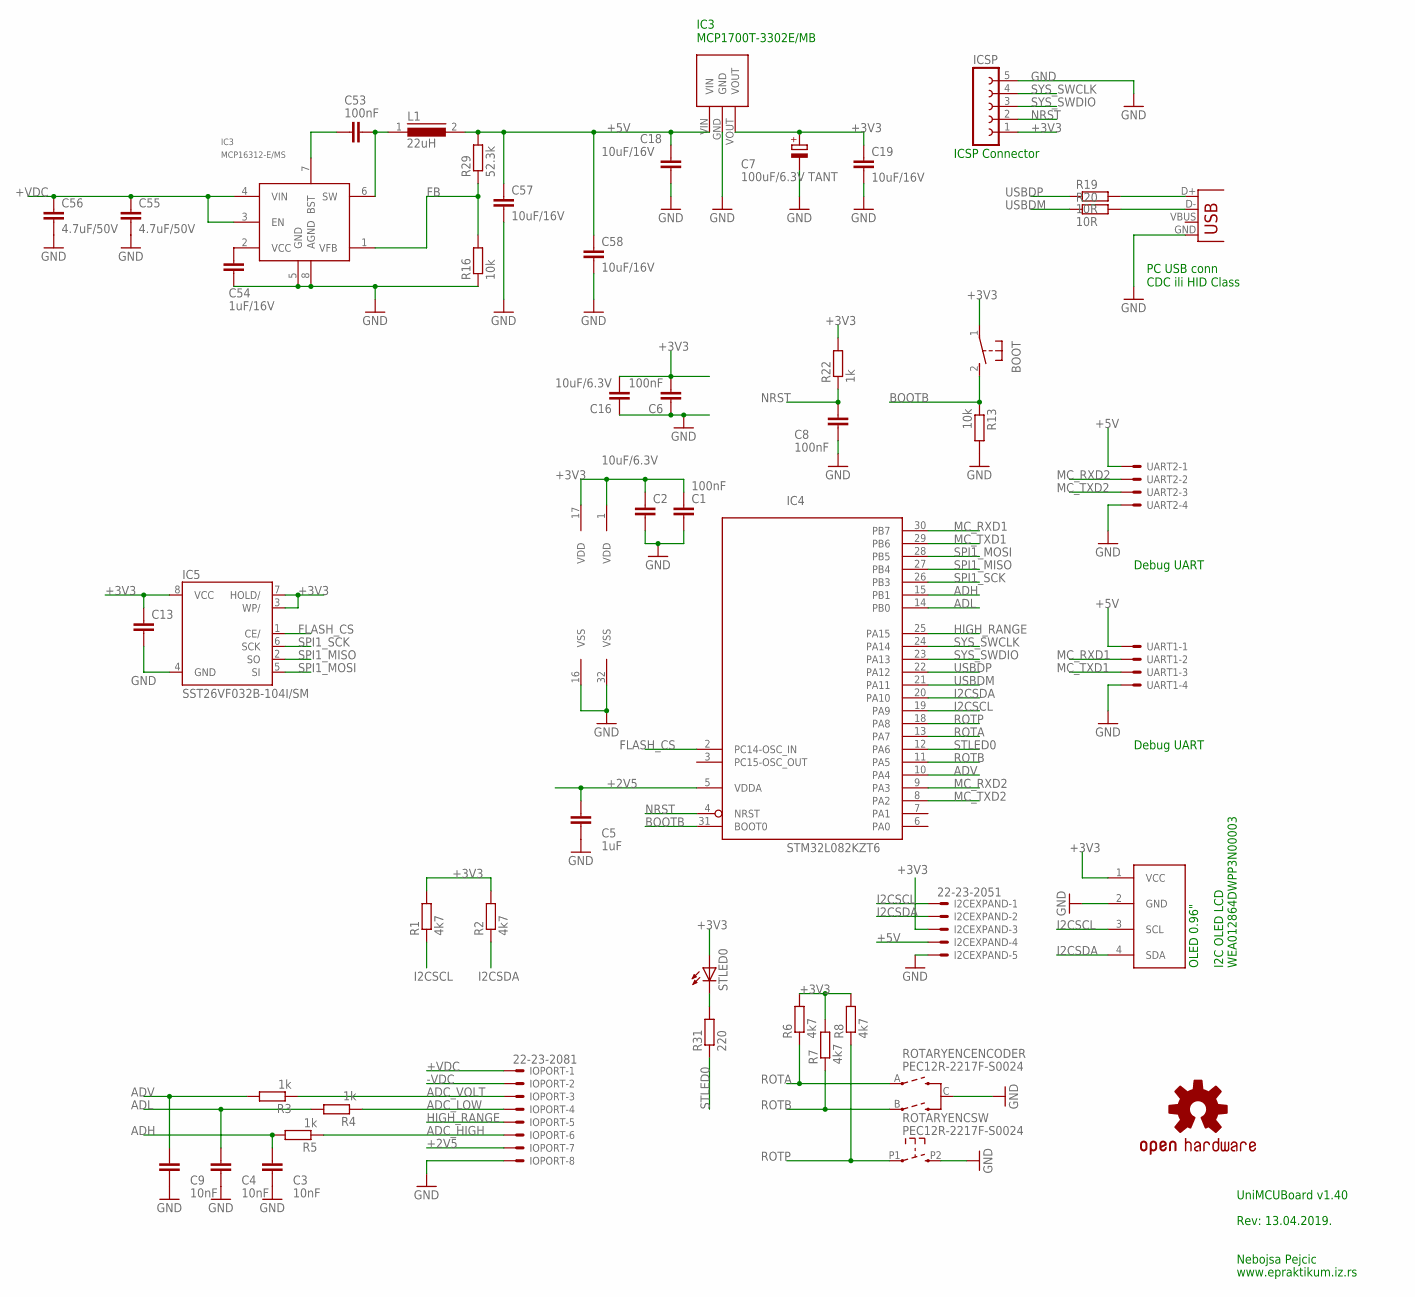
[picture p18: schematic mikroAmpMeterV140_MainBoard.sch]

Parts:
BOOT: 31-XX; B3F-31XX
C1, C6, C8, C53: 100nF; C0603
C2, C16: 10uF/6.3V; C0603
C3, C4, C9: 10nF; C0603
C5: 1uF; C0603
C7: 100uF/6.3V TANT; SMC_B
C13: 100n; C0603
C18, C19: 10uF/16V; C0603
C54: 1uF/16V; C0603
C55, C56: 4.7uF/50V; C1210
C57, C58: 10uF/16V; C0805
I2CEXPAND: 22-23-2051
IC3: MCP16312-E/MS; MSOP8
IC4: STM32L082KZT6; LQFP32
IC5: SST26VF032B-104I/SM; SOIC8
IC7: MCP1700T-3302E/MB; SOT89
ICSP: FE05-1
IOPORT: 22-23-2081
L1: 22uH; DR73
LOGO1: OSHW-LOGOM; OSHW-LOGO-M
OLED1: WEA012864DWPP3N00003; I2C_OLED_PACKAGE
R1, R2, R6, R7, R8: 4k7; R0603
R3, R4, R5, R22: 1k; R0603
R13: 10k; R0603
R16: 10k; R0805
R19, R20: 10R; R0603
R29: 52.3k; R0805
R31: 220; R0603
ROTARYENC: PEC12R-2217F-S0024; PEC12_INCREMENTAL_ENCODER
STLED0: LEDCHIPLED_1206; CHIPLED_1206
UART1, UART2: 22-23-2041
USB: USB-MB-S

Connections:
+2V5: C5.1, IC4.5 (VDDA), IOPORT.7
+3V3: BOOT.1, C1.1, C2.1, C6.2, C7.+, C13.2, C16.2, C19.1, I2CEXPAND.3, IC4.1 (VDD), IC4.17 (VDD), IC5.3 (WP/), IC5.7 (HOLD/), IC5.8 (VCC), IC7.VOUT, ICSP.1, OLED1.1 (VCC), R1.2, R2.2, R6.2, R7.2, R8.2, R22.2, STLED0.A
+5V: C18.1, C57.1, C58.1, I2CEXPAND.4, IC7.VIN, L1.2, R29.2, UART1.1, UART2.1
+VDC: C55.1, C56.1, IC3.3 (EN), IC3.4 (VIN), IOPORT.1
-VDC: IOPORT.2
ADC_HIGH: IOPORT.6, R5.1
ADC_LOW: IOPORT.4, R4.1
ADC_VOLT: IOPORT.3, R3.1
ADH: C3.1, IC4.15 (PB1), R5.2
ADL: C4.1, IC4.14 (PB0), R4.2
ADV: C9.1, IC4.10 (PA4), R3.2
BOOTB: BOOT.2 (S), IC4.31 (BOOT0), R13.1
FB: IC3.1 (VFB), R16.2, R29.1
FLASH_CS: IC4.2 (PC14-OSC_IN), IC5.1 (CE/)
GND: C1.2, C2.2, C3.2, C4.2, C5.2, C6.1, C7.-, C8.1, C9.2, C13.1, C16.1, C18.2, C19.2, C54.1, C55.2, C56.2, C57.2, C58.2, I2CEXPAND.5, IC3.5 (GND), IC3.8 (AGND), IC4.16 (VSS), IC4.32 (VSS), IC5.4 (GND), IC7.GND, ICSP.5, IOPORT.8, OLED1.2 (GND), R13.2, R16.1, ROTARYENC.C, ROTARYENC.P2 (2), UART1.4, UART2.4, USB.GND
HIGH_RANGE: IC4.25 (PA15), IOPORT.5
I2CSCL: I2CEXPAND.1, IC4.19 (PA9), OLED1.3 (SCL), R1.1
I2CSDA: I2CEXPAND.2, IC4.20 (PA10), OLED1.4 (SDA), R2.1
MC_RXD1: IC4.30 (PB7), UART1.2
MC_RXD2: IC4.9 (PA3), UART2.2
MC_TXD1: IC4.29 (PB6), UART1.3
MC_TXD2: IC4.8 (PA2), UART2.3
unnamed: R19.2, USB.D+
unnamed: R20.2, USB.D-
unnamed: C53.1, IC3.7 (BST)
unnamed: C54.2, IC3.2 (VCC)
NRST: C8.2, IC4.4 (NRST), ICSP.2, R22.1
ROTA: IC4.13 (PA7), R6.1, ROTARYENC.A
ROTB: IC4.11 (PA5), R7.1, ROTARYENC.B
ROTP: IC4.18 (PA8), R8.1, ROTARYENC.P1 (1)
SPI1_MISO: IC4.27 (PB4), IC5.2 (SO)
SPI1_MOSI: IC4.28 (PB5), IC5.5 (SI)
SPI1_SCK: IC4.26 (PB3), IC5.6 (SCK)
STAT_LED: R31.2, STLED0.C
STLED0: IC4.12 (PA6), R31.1
SW: C53.2, IC3.6 (SW), L1.1
SYS_SWCLK: IC4.24 (PA14), ICSP.4
SYS_SWDIO: IC4.23 (PA13), ICSP.3
USBDM: IC4.21 (PA11), R20.1
USBDP: IC4.22 (PA12), R19.1

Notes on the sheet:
ICSP Connector
IC3 MCP1700T-3302E/MB
UniMCUBoard v1.40
Nebojsa Pejcic
Rev: 13.04.2019.
www.epraktikum.iz.rs
PC USB conn CDC ili HID Class
Debug UART
I2C OLED LCD WEA012864DWPP3N00003
OLED 0.96"

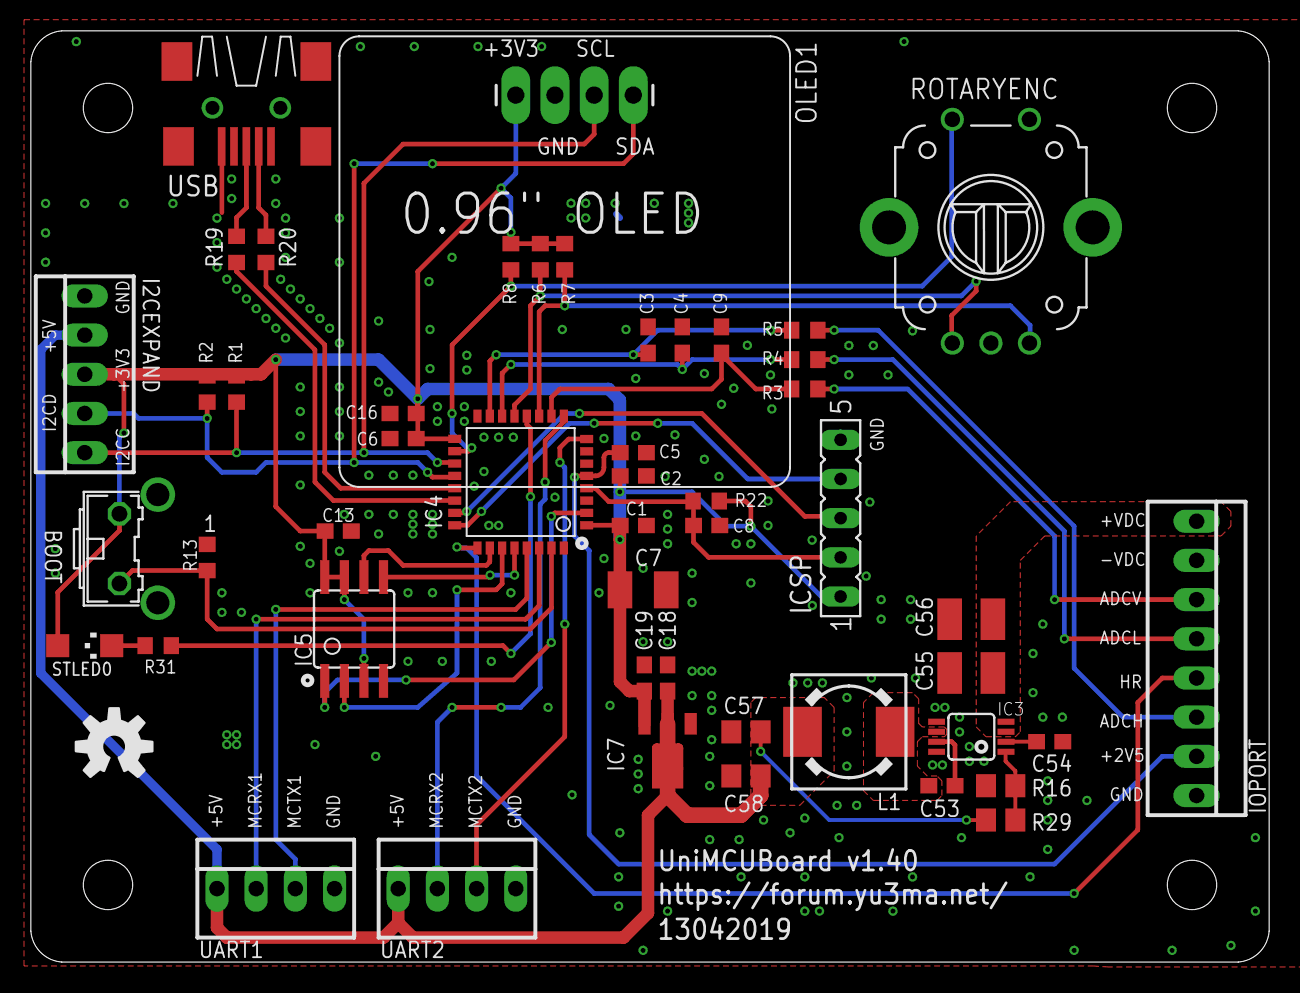
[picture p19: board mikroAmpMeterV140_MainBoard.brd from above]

Board: 2 copper layers, 80.3 x 60.4 mm, 50 parts (0 on the bottom side), 39 nets.

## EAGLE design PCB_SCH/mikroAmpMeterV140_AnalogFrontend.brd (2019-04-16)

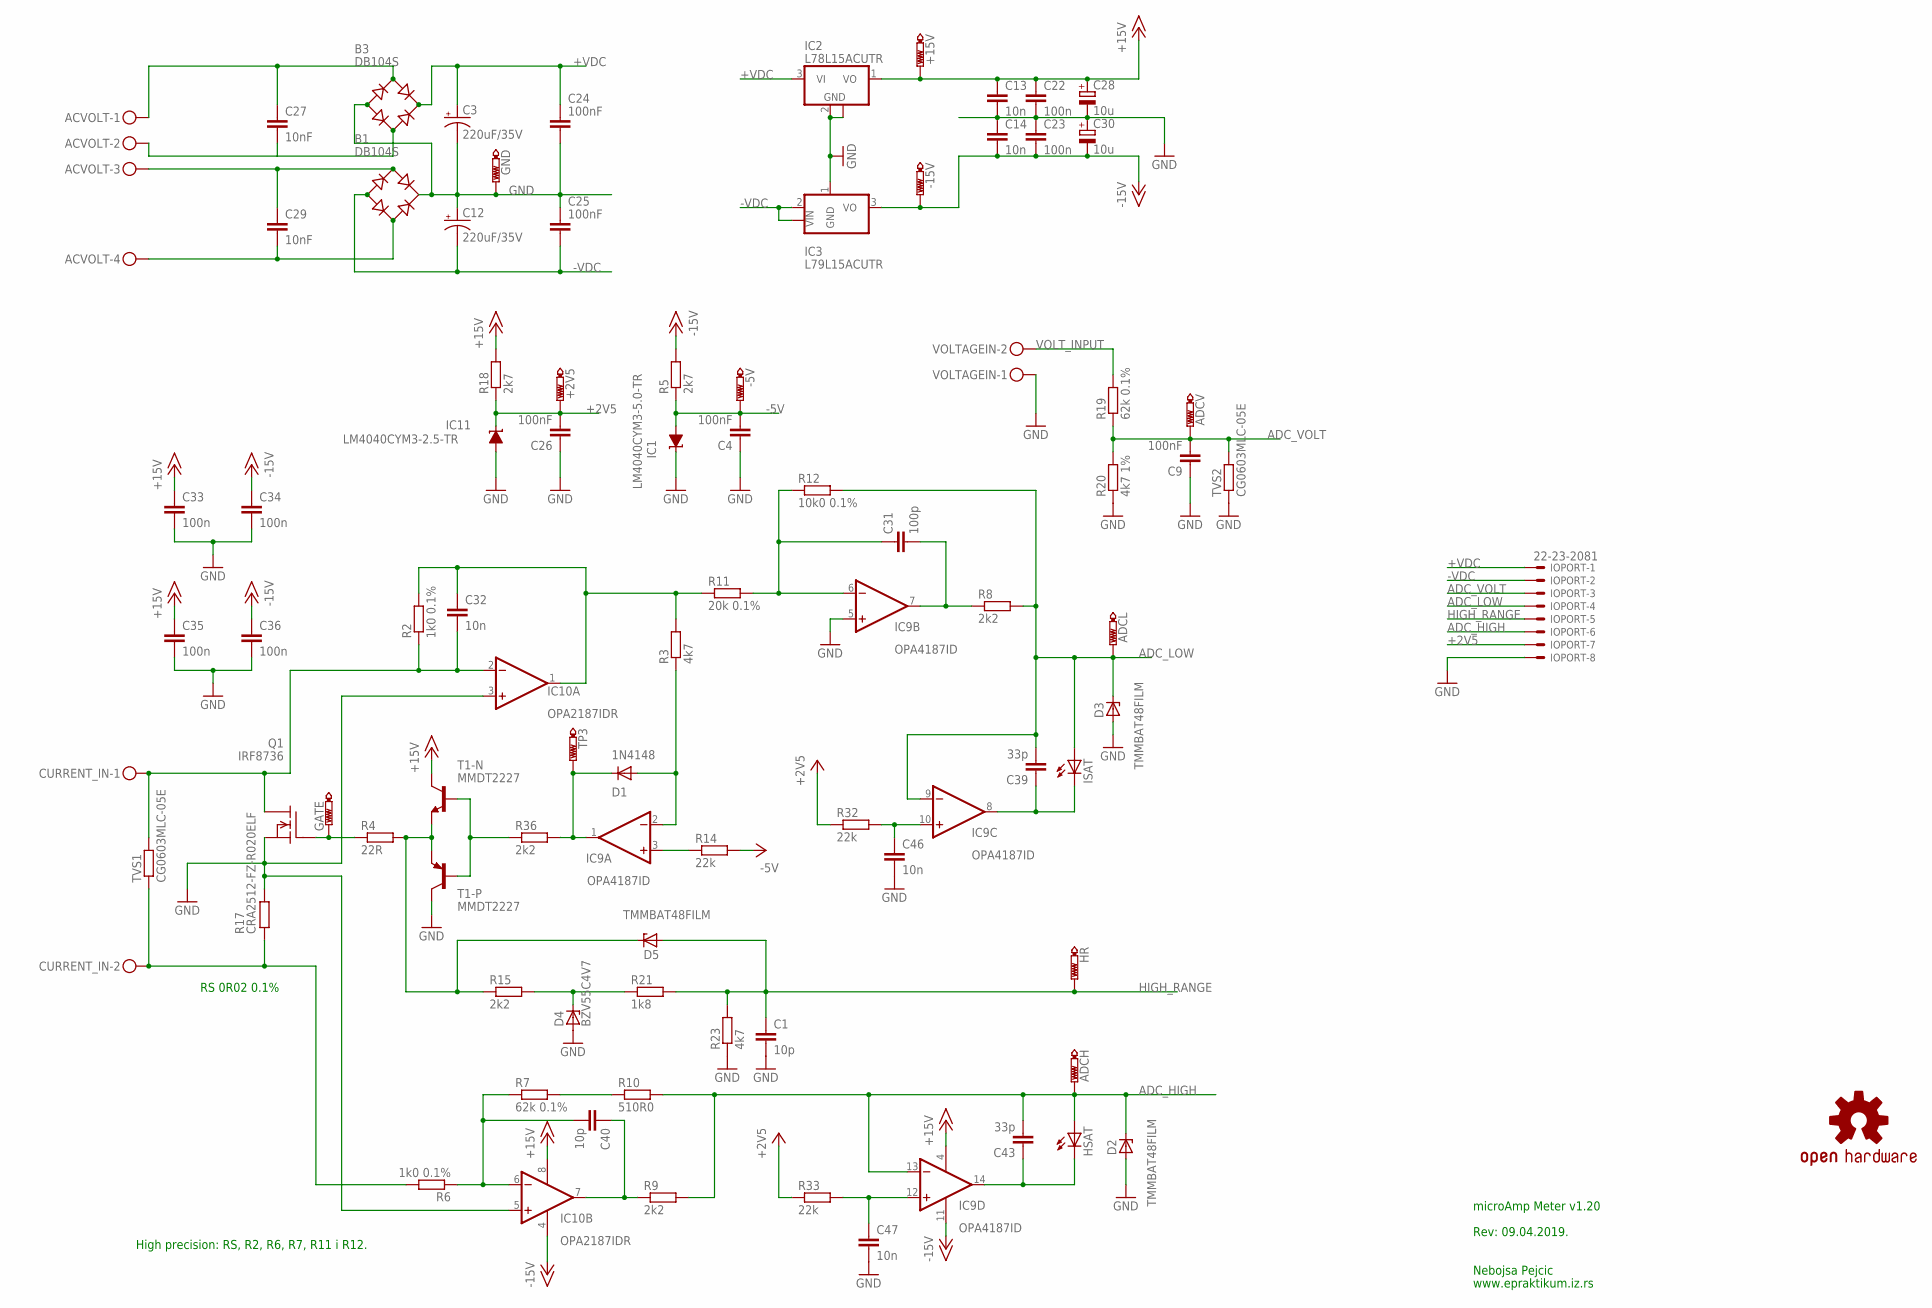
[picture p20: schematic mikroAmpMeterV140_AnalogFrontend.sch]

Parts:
+2V5, +15V: PTR1TP15R; TP15R
-5V, -15V: PTR1TP15R; TP15R
ACVOLT: MKDSN1,5/4-5,08
ADCH: PTR1TP15R; TP15R
ADCL: PTR1TP15R; TP15R
ADCV: PTR1TP15R; TP15R
B1, B3: DB104S; DBS
C1, C40: 10p; C0805
C3, C12: 220uF/35V; 153CLV-1014
C4, C9, C24, C25, C26: 100nF; C0805
C13, C14, C32, C46, C47: 10n; C0805
C22, C23, C33, C34, C35, C36: 100n; C0805
C27, C29: 10nF; C1206
C28, C30: 10u; UD-6,3X7,7_NICHICON
C31: 100p; C0805
C39, C43: 33p; C0805
CURRENT_IN: MKDSN1,5/2-5,08
D1: 1N4148; SOD80C
D2, D3, D5: TMMBAT48FILM; SOD80C
D4: BZV55C4V7; SOD80C
GATE: PTR1TP15R; TP15R
GND: PTR1TP15R; TP15R
HR: PTR1TP15R; TP15R
HSAT: LEDCHIPLED_1206; CHIPLED_1206
IC1: LM4040CYM3-5.0-TR; DBZ_R-PDSO-G3
IC2: L78L15ACUTR; SOT89
IC3: L79L15ACUTR; SOT89
IC9: OPA4187ID; SO14
IC10: OPA2187IDR; SO08@1
IC11: LM4040CYM3-2.5-TR; DBZ_R-PDSO-G3
IOPORT: 22-23-2081
ISAT: LEDCHIPLED_1206; CHIPLED_1206
LOGO1: OSHW-LOGOM; OSHW-LOGO-M
Q1: IRF8736; SO-8
R2, R6: 1k0 0.1%; R0805
R3, R23: 4k7; R0805
R4: 22R; R0805
R5, R18: 2k7; R0805
R7, R19: 62k 0.1%; R0805
R8, R9, R15, R36: 2k2; R0805
R10: 510R0; R0805
R11: 20k 0.1%; R0805
R12: 10k0 0.1%; R0805
R14, R32, R33: 22k; R0805
R17: CRA2512-FZ-R020ELF; R2512
R20: 4k7 1%; R0805
R21: 1k8; R0805
T1: MMDT2227; SOT363
TP3: PTR1TP15R; TP15R
TVS1, TVS2: CG0603MLC-05E; R0805
VOLTAGEIN: MKDSN1,5/2-5,08; MPN MKDSN 1,5/2-5.08

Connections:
+2V5: +2V5.TP, C26.2, IC11.1 (C), IOPORT.7, R18.1, R32.1, R33.1
+15V: +15V.TP, C13.1, C22.1, C28.+, C33.1, C35.1, IC2.1 (VO), IC9.4 (V+), IC10.8 (V+), R18.2, T1.6 (C)
+VDC: B3.+, C3.+, C24.2, IC2.3 (VI), IOPORT.1
-5V: -5V.TP, C4.2, IC1.2 (A), R5.1, R14.2
-15V: -15V.TP, C14.2, C23.2, C30.-, C34.1, C36.1, IC3.3 (VO), IC9.11 (V-), IC10.4 (V-), R5.2
-VDC: B1.-, C12.-, C25.1, IC3.2 (VIN), IC3.2@1 (VIN), IOPORT.2
ADC_HIGH: ADCH.TP, C43.2, D2.C, HSAT.A, IC9.13 (-IN), IOPORT.6, R9.2, R10.2
ADC_LOW: ADCL.TP, C39.2, D3.C, IC9.9 (-IN), IOPORT.4, ISAT.A, R8.2, R12.2
ADC_VOLT: ADCV.TP, C9.2, IOPORT.3, R19.1, R20.2, TVS2.2
CIN+: C32.2, CURRENT_IN.1, IC10.2 (-IN), Q1.5 (D), Q1.6 (D), Q1.7 (D), Q1.8 (D), R2.1, TVS1.2
CIN-: CURRENT_IN.2, R6.2, R17.1, TVS1.1
GND: B1.+, B3.-, C1.2, C3.-, C4.1, C9.1, C12.+, C13.2, C14.1, C22.2, C23.1, C24.1, C25.2, C26.1, C28.-, C30.+, C33.2, C34.2, C35.2, C36.2, C46.2, C47.2, D2.A, D3.A, D4.A, GND.TP, IC1.1 (C), IC2.2 (GND), IC2.2@1 (GND), IC3.1 (GND), IC9.5 (+IN), IC10.3 (+IN), IC10.5 (+IN), IC11.2 (A), IOPORT.8, Q1.1 (S), Q1.2 (S), Q1.3 (S), R17.2, R20.1, R23.1, T1.3 (C), TVS2.1, VOLTAGEIN.1
HIGH_RANGE: C1.1, D5.A, HR.TP, IOPORT.5, R21.2, R23.2
unnamed: IC9.3 (+IN), R14.1
unnamed: C32.1, IC10.1 (OUT), R2.2, R3.2, R11.1
unnamed: C31.1, IC9.6 (-IN), R11.2, R12.1
unnamed: C31.2, IC9.7 (OUT), R8.1
unnamed: ACVOLT.1, B3.AC1, C27.2
unnamed: ACVOLT.2, B3.AC2, C27.1
unnamed: ACVOLT.3, B1.AC1, C29.2
unnamed: ACVOLT.4, B1.AC2, C29.1
unnamed: GATE.TP, Q1.4 (G), R4.1
unnamed: D5.C, R4.2, R15.1, T1.1 (E), T1.4 (E)
unnamed: R36.1, T1.2 (B), T1.5 (B)
unnamed: D1.C, IC9.1 (OUT), R36.2, TP3.TP
unnamed: D1.A, IC9.2 (-IN), R3.1
unnamed: D4.C, R15.2, R21.1
unnamed: C39.1, IC9.8 (OUT), ISAT.C
unnamed: C40.2, IC10.6 (-IN), R6.1, R7.1
unnamed: R7.2, R10.1
unnamed: C40.1, IC10.7 (OUT), R9.1
unnamed: C43.1, HSAT.C, IC9.14 (OUT)
unnamed: C47.1, IC9.12 (+IN), R33.2
unnamed: C46.1, IC9.10 (+IN), R32.2
VOLT_INPUT: R19.2, VOLTAGEIN.2

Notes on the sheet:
microAmp Meter v1.20
Nebojsa Pejcic
Rev: 09.04.2019.
www.epraktikum.iz.rs
High precision: RS, R2, R6, R7, R11 i R12.
RS 0R02 0.1%

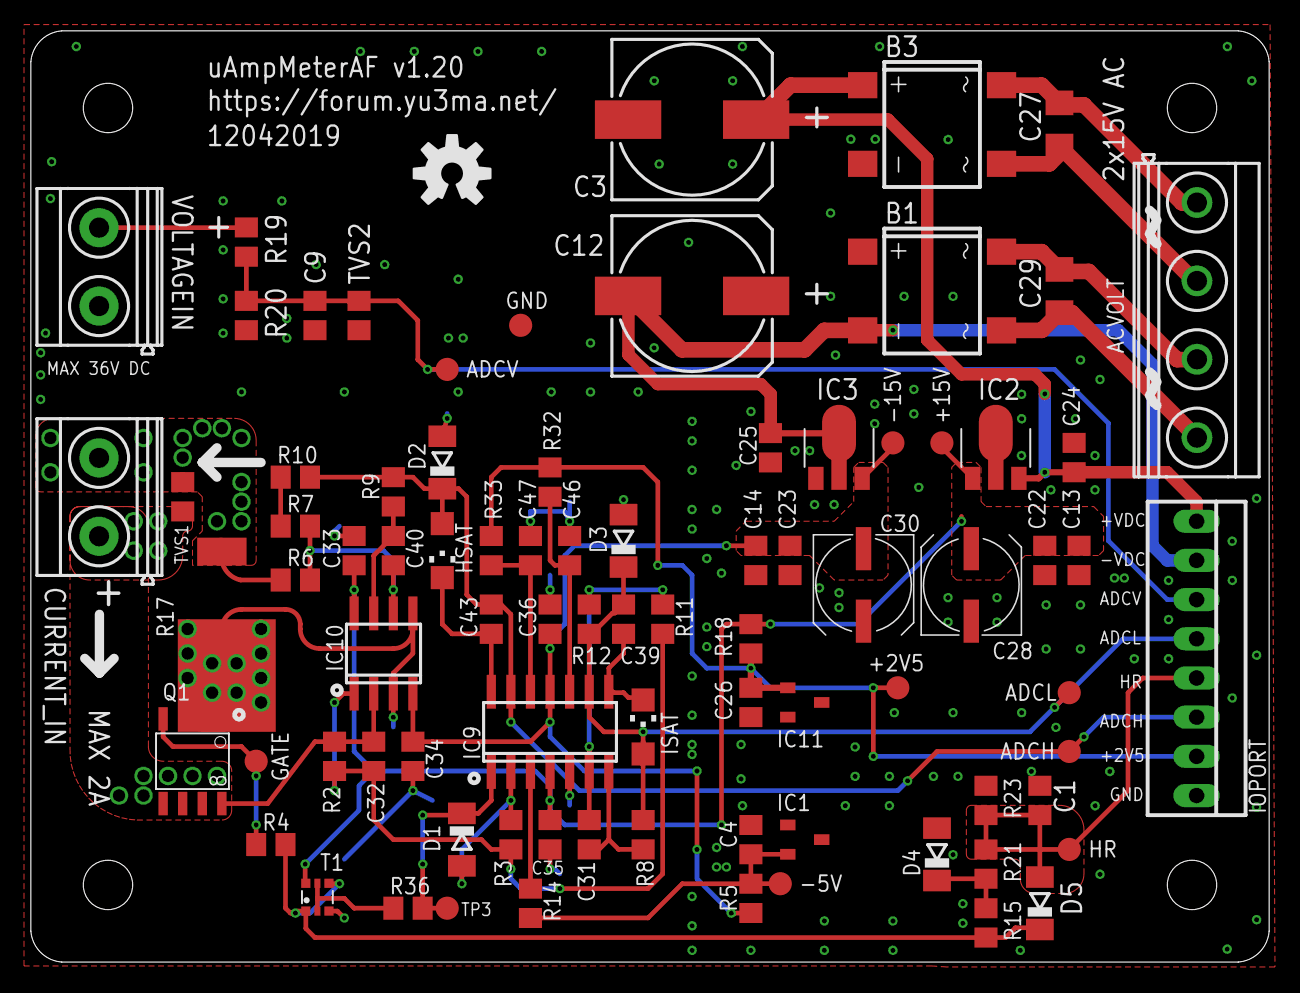
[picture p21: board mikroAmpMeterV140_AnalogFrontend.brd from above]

Board: 2 copper layers, 80.3 x 60.4 mm, 84 parts (0 on the bottom side), 35 nets.

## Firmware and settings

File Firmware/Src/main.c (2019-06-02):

/**
  ******************************************************************************
  * @file           : main.c
  * @brief          : Main program body
  ******************************************************************************
  * This notice applies to any and all portions of this file
  * that are not between comment pairs USER CODE BEGIN and
  * USER CODE END. Other portions of this file, whether 
  * inserted by the user or by software development tools
  * are owned by their respective copyright owners.
  *
  * Copyright (c) 2019 STMicroelectronics International N.V. 
  * All rights reserved.
  *
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
  ******************************************************************************
  */
/* Includes ------------------------------------------------------------------*/
#include "main.h"
#include "stm32l0xx_hal.h"
#include "usb_device.h"

/* USER CODE BEGIN Includes */
#include "ssd1306.h"

/* USER CODE END Includes */

ADC_HandleTypeDef hadc;
DMA_HandleTypeDef hdma_adc;

I2C_HandleTypeDef hi2c1;

IWDG_HandleTypeDef hiwdg;

SPI_HandleTypeDef hspi1;

TIM_HandleTypeDef htim6;
TIM_HandleTypeDef htim7;
TIM_HandleTypeDef htim22;

UART_HandleTypeDef huart1;
UART_HandleTypeDef huart2;

/* USER CODE BEGIN PV */
uint32_t OldTick100ms = 0;

///////// ADC Variables and Settings
#define ADC_NUMBER_OF_CHANNELS 5u
#define ADC_NUMBER_OF_SAMPLES 32u
#define ADC_ARRAY_SIZE (ADC_NUMBER_OF_CHANNELS * ADC_NUMBER_OF_SAMPLES) // 3 Channels and 32 samples 

#define ADC_ADV 			0u 	// Voltage 						PA4 / AD CHANNEL 4
#define ADC_ADL				1u	// Current Low range 	PB0 / AD CHANNEL 8 
#define ADC_ADH				2u 	// Current High range	PB9 / AD CHANNEL 9
#define ADC_INTVREF		3u	// Internal Channel
#define ADC_INTEMPE		4u	// Internal Channel


unsigned long ADCDmaBuffer[ADC_ARRAY_SIZE];
unsigned char ADCDone = 0;

_VoltageMeasurement_type	VoltageMeasurement;
_CurrentMeasurement_type	CurrentMeasurement;

// Display Variables
unsigned char DisplayPage = MAIN_DISPLAY_PAGE0;
unsigned char DisplayClrScr = 0;

volatile unsigned long SecondsTimer = 0;

/* USER CODE END PV */

void SystemClock_Config(void);
static void MX_GPIO_Init(void);
static void MX_DMA_Init(void);
static void MX_ADC_Init(void);
static void MX_I2C1_Init(void);
static void MX_IWDG_Init(void);
static void MX_TIM6_Init(void);
static void MX_TIM7_Init(void);
static void MX_USART1_UART_Init(void);
static void MX_USART2_UART_Init(void);
static void MX_TIM22_Init(void);
static void MX_SPI1_Init(void);

/* USER CODE BEGIN PFP */
unsigned char GetANFHighRangeStatus(void);
void SetStatusLED(unsigned char LedState);


/* USER CODE END PFP */

/* USER CODE BEGIN 0 */

void HAL_SYSTICK_Callback(void)
{
	static unsigned int Count1sec = 0;
	
	if(++Count1sec >= 1000)
	{
		Count1sec = 0;
	  SecondsTimer++;
	}
}
		
// ADC ConvCallback
void HAL_ADC_ConvCpltCallback(ADC_HandleTypeDef* hadc1)
{
	HAL_ADC_Stop_DMA(&hadc);
	ADCDone = 1;	
}

// Ovde radimo merenje napona sa AD konvertora
void ADTasks(void)
{
	unsigned long ADCRawAcu[ADC_NUMBER_OF_CHANNELS];
	unsigned short ADCRawFiltered[ADC_NUMBER_OF_CHANNELS];
	unsigned char Pointer, Sample;
	
	if(ADCDone == 0)
		return;
	
	ADCDone = 0;
			
	// Get results from DMA buffer
	ADCRawAcu[ADC_ADV] = 0;
	ADCRawAcu[ADC_ADL] = 0;
	ADCRawAcu[ADC_ADH] = 0;
	
	ADCRawAcu[ADC_INTEMPE] = 0;
	ADCRawAcu[ADC_INTVREF] = 0;

	Pointer = 0;
	
	for(Sample=0; Sample<ADC_NUMBER_OF_SAMPLES; Sample++)
	{
		
		ADCRawAcu[ADC_ADV] += ADCDmaBuffer[Pointer + 0];
		ADCRawAcu[ADC_ADL] += ADCDmaBuffer[Pointer + 1];
		ADCRawAcu[ADC_ADH] += ADCDmaBuffer[Pointer + 2];
		ADCRawAcu[ADC_INTEMPE] += ADCDmaBuffer[Pointer + 3];
		ADCRawAcu[ADC_INTVREF] += ADCDmaBuffer[Pointer + 4];
		
		Pointer += ADC_NUMBER_OF_CHANNELS;
	}

	ADCRawFiltered[ADC_ADV] = ADCRawAcu[ADC_ADV] / ADC_NUMBER_OF_SAMPLES;
	ADCRawFiltered[ADC_ADL] = ADCRawAcu[ADC_ADL] / ADC_NUMBER_OF_SAMPLES;
	ADCRawFiltered[ADC_ADH] = ADCRawAcu[ADC_ADH] / ADC_NUMBER_OF_SAMPLES;
	ADCRawFiltered[ADC_INTEMPE] = ADCRawAcu[ADC_INTEMPE] / ADC_NUMBER_OF_SAMPLES;
	ADCRawFiltered[ADC_INTVREF] = ADCRawAcu[ADC_INTVREF] / ADC_NUMBER_OF_SAMPLES;
	
	VoltageMeasurement.ADCRaw = ADCRawFiltered[ADC_ADV];
	CurrentMeasurement.ADCLChRaw = ADCRawFiltered[ADC_ADL];	
	CurrentMeasurement.ADCHChRaw = ADCRawFiltered[ADC_ADH];
	
	/////////////////
	
	// This starts the ADC in interrupt mode
	HAL_ADC_Start_DMA(&hadc, (uint32_t*)&ADCDmaBuffer, ADC_ARRAY_SIZE);
	
	/////////////////
	
	// Measure Voltage Calculation 
	#define RESISTOR_DIVIDER_UP	62.00 // 62k 0.1%
	#define RESISTOR_DIVIDER_DN	 4.70 // 4k7 0.1%
	
	float DividerRatio = (float)RESISTOR_DIVIDER_DN/((float)RESISTOR_DIVIDER_UP + (float)RESISTOR_DIVIDER_DN); 
	VoltageMeasurement.ADCAverage = (float)VoltageMeasurement.ADCRaw * ((float)AD_REFERENCE/(float)AD_RESOLUTION) / (float) DividerRatio; // 

	VoltageMeasurement.Cumulative += VoltageMeasurement.ADCAverage;

	// Measure Current Calculation ADL
	#define ADC_LO_RANGE_CURRENT	0.005 // 5mA
	#define ADC_LO_RANGE_VOLTAGE	2.500 // 2.5V

	#define ADC_HI_RANGE_CURRENT	2.000 // 2A
	#define ADC_HI_RANGE_VOLTAGE	2.500 // 2.5V

	CurrentMeasurement.ADCLChAverage = (float)CurrentMeasurement.ADCLChRaw * ((float)AD_REFERENCE/(float)AD_RESOLUTION) * (float)ADC_LO_RANGE_CURRENT / (float)ADC_LO_RANGE_VOLTAGE; // 

	// Measure Current Calculation ADL
	CurrentMeasurement.ADCHChAverage = (float)CurrentMeasurement.ADCHChRaw * ((float)AD_REFERENCE/(float)AD_RESOLUTION) * (float)ADC_HI_RANGE_CURRENT / (float)ADC_HI_RANGE_VOLTAGE; // 
	
	// Cumulative ADC measurements // Sample period 100ms
	if(GetANFHighRangeStatus() == ANF_HIGH_RANGE)
	{
		// HIGH RANGE

		SetStatusLED(LED_ON);

		CurrentMeasurement.ADCHCumulative += CurrentMeasurement.ADCHChAverage;
	}
	else
	{
		// LOW RANGE

		SetStatusLED(LED_OFF);

		CurrentMeasurement.ADCLCumulative += CurrentMeasurement.ADCLChAverage;
	}

	CurrentMeasurement.Samples ++;

}

void ShowDisplayTask(void)
{
	char LCDBuf[32];
	
	if(DisplayClrScr)
	{
		DisplayClrScr = 0;
		
		ssd1306_Fill(White);
		ssd1306_UpdateScreen();
	}

	switch (DisplayPage)
	{
		case MAIN_DISPLAY_PAGE0:
		{
			ssd1306_SetCursor(5,5);
			ssd1306_WriteString("mikroAMP V1",Font_11x18,Black);
			
			sprintf(LCDBuf, "Ihigh: %3.3fA", CurrentMeasurement.ADCHChAverage);
			ssd1306_SetCursor(5,24);
			ssd1306_WriteString(LCDBuf, Font_7x10,Black);

			sprintf(LCDBuf, "Ilow: %3.3fmA", CurrentMeasurement.ADCLChAverage * 1000.00);
			ssd1306_SetCursor(5,35);
			ssd1306_WriteString(LCDBuf, Font_7x10,Black);

			sprintf(LCDBuf, "Volt:%3.3fV", VoltageMeasurement.ADCAverage);
			ssd1306_SetCursor(5,46);
			ssd1306_WriteString(LCDBuf, Font_7x10,Black);
		}
		break;
		
		case MAIN_DISPLAY_PAGE1:
		{
			sprintf(LCDBuf, "Ih: %3.3fA", CurrentMeasurement.ADCHChAverage);
			ssd1306_SetCursor(5,10);
			ssd1306_WriteString(LCDBuf, Font_11x18,Black);

			sprintf(LCDBuf, "Il: %3.3fmA", CurrentMeasurement.ADCLChAverage * 1000.00);
			ssd1306_SetCursor(5,38);
			ssd1306_WriteString(LCDBuf, Font_11x18,Black);


		}
		break;		
		
		case MAIN_DISPLAY_PAGE2:
		{
			sprintf(LCDBuf, "Ihigh [A]");
			ssd1306_SetCursor(5, 5);
			ssd1306_WriteString(LCDBuf, Font_11x18, Black);

			sprintf(LCDBuf, "%3.3f", CurrentMeasurement.ADCHChAverage);
			ssd1306_SetCursor(5, 32);
			ssd1306_WriteString(LCDBuf, Font_16x26, Black);
		}
		break;			

		case MAIN_DISPLAY_PAGE3:
		{
			sprintf(LCDBuf, "Ilow [mA]");
			ssd1306_SetCursor(5, 5);
			ssd1306_WriteString(LCDBuf, Font_11x18, Black);

			sprintf(LCDBuf, "%3.3f", CurrentMeasurement.ADCLChAverage * 1000.00);
			ssd1306_SetCursor(5, 32);
			ssd1306_WriteString(LCDBuf, Font_16x26, Black);
		}
		break;			

		case MAIN_DISPLAY_PAGE4:
		{
			sprintf(LCDBuf, "Voltage [V]");
			ssd1306_SetCursor(5, 5);
			ssd1306_WriteString(LCDBuf, Font_11x18, Black);

			sprintf(LCDBuf, "%3.3f", VoltageMeasurement.ADCAverage);
			ssd1306_SetCursor(5, 32);
			ssd1306_WriteString(LCDBuf, Font_16x26,Black);
		}
		break;		
		
		case MAIN_DISPLAY_PAGE5: // Average Current summ in period of time
		{
			sprintf(LCDBuf, "Average:");
			ssd1306_SetCursor(5, 5);
			ssd1306_WriteString(LCDBuf, Font_11x18, Black);
			
			float CurrentCumulativeCalc;
			CurrentCumulativeCalc = ((float)CurrentMeasurement.ADCHCumulative + (float)CurrentMeasurement.ADCLCumulative) * 1000.00;
			CurrentCumulativeCalc /= (float)CurrentMeasurement.Samples; // We have 100ms sampling period, so must divide for 1sec resolution
			
			sprintf(LCDBuf, "%3.3f mA", CurrentCumulativeCalc);
			ssd1306_SetCursor(5, 25);
			ssd1306_WriteString(LCDBuf, Font_11x18,Black);

			unsigned char TimeHours;
			unsigned char TimeMinutes;
			unsigned char TimeSeconds;
			
			TimeHours = SecondsTimer / 3600;
			TimeMinutes = (SecondsTimer / 60) % 60;
			TimeSeconds = SecondsTimer % 60;
			
			sprintf(LCDBuf, "%02d:%02d:%02d", TimeHours, TimeMinutes, TimeSeconds);
			ssd1306_SetCursor(5, 43);
			ssd1306_WriteString(LCDBuf, Font_11x18,Black);
		}
		break;			

		case MAIN_DISPLAY_PAGE6:
		{
			ssd1306_SetCursor(5,5);
			ssd1306_WriteString(DEVICE_NAME,Font_11x18,Black);
			
			sprintf(LCDBuf, FIRMWARE_VERSION);
			ssd1306_SetCursor(5,24);
			ssd1306_WriteString(LCDBuf, Font_7x10,Black);

			sprintf(LCDBuf, HARDWARE_VERSION);
			ssd1306_SetCursor(5,35);
			ssd1306_WriteString(LCDBuf, Font_7x10,Black);

			sprintf(LCDBuf, WEBSITE_INFO);
			ssd1306_SetCursor(5,46);
			ssd1306_WriteString(LCDBuf, Font_7x10,Black);
		}
		break;
		
		default:
			sprintf(LCDBuf, "Unknown page");
			ssd1306_SetCursor(0,5);
			ssd1306_WriteString(LCDBuf, Font_7x10,Black);
			break;
		
	}
	
	ssd1306_UpdateScreen();
}

void ButtonTask(void)
{
	static unsigned char Debounce = 0;
	static unsigned char ButtonIsPressedCnt = 0;
	
	if(HAL_GPIO_ReadPin(ROTP_GPIO_Port, ROTP_Pin) == GPIO_PIN_RESET) // Button is pressed
	{
		if(++ButtonIsPressedCnt > 30) // If button is pressed more than 5 seconds
		{
			ButtonIsPressedCnt = 30;
			
			if(DisplayPage == MAIN_DISPLAY_PAGE5) // Average Current Reset
			{
				// Reset Timer and Cumulative varibles
				SecondsTimer = 0;
				
				CurrentMeasurement.ADCHCumulative = 0.0;
				CurrentMeasurement.ADCLCumulative = 0.0;
				CurrentMeasurement.Samples = 0;
			}
		}
	}
	else
	{
		if((ButtonIsPressedCnt > 0) && (ButtonIsPressedCnt < 20)) // Short Button Press
		{
			if(++DisplayPage > MAIN_DISPLAY_LAST_PAGE)
				DisplayPage = MAIN_DISPLAY_PAGE0;
				
			DisplayClrScr = 1;
		}

		ButtonIsPressedCnt = 0;

	}
}

unsigned char GetANFHighRangeStatus(void)
{	
	if(HAL_GPIO_ReadPin(HIGH_RANGE_GPIO_Port, HIGH_RANGE_Pin) == GPIO_PIN_RESET) // High range is detected
	{
		return(ANF_HIGH_RANGE);
	}
	else
	{
		return(ANF_LOW_RANGE);
	}
}

void SetStatusLED(unsigned char LedState)
{
	if(LedState == LED_ON)
	{
		HAL_GPIO_WritePin(STLED0_GPIO_Port, STLED0_Pin, GPIO_PIN_RESET); // Inverted Becouse LED is connected to Power +VDD
	}
	else
	{
		HAL_GPIO_WritePin(STLED0_GPIO_Port, STLED0_Pin, GPIO_PIN_SET); // Inverted Becouse LED inverted to Power +VDD
	}
}

/* USER CODE END 0 */

/**
  * @brief  The application entry point.
  *
  * @retval None
  */
int main(void)
{
  /* MCU Configuration----------------------------------------------------------*/

  /* Reset of all peripherals, Initializes the Flash interface and the Systick. */
  HAL_Init();

  /* Configure the system clock */
  SystemClock_Config();

  /* Initialize all configured peripherals */
  MX_GPIO_Init();
  MX_DMA_Init();
  MX_ADC_Init();
  MX_I2C1_Init();
  //MX_IWDG_Init();
  MX_TIM6_Init();
  MX_TIM7_Init();
  MX_USART1_UART_Init();
  MX_USART2_UART_Init();
  MX_USB_DEVICE_Init();
  MX_TIM22_Init();
  MX_SPI1_Init();
  /* USER CODE BEGIN 2 */
	
	// ADC Callibration and start
	HAL_ADCEx_Calibration_Start(&hadc, ADC_SINGLE_ENDED);

	// This starts the ADC in interrupt mode
	HAL_ADC_Start_DMA(&hadc, (uint32_t*)&ADCDmaBuffer, ADC_ARRAY_SIZE);

	HAL_TIM_Base_Start(&htim22); // Used for ADC sample time

	// OLED Display Init
	ssd1306_Init();
	
	HAL_Delay(1000);
  ssd1306_Fill(White);
  ssd1306_UpdateScreen();

  HAL_Delay(1000);

	// Variables initialisation
	CurrentMeasurement.ADCHCumulative = 0.0;
	CurrentMeasurement.ADCLCumulative = 0.0;
	VoltageMeasurement.Cumulative = 0.0;
	CurrentMeasurement.Samples = 0;

  /* USER CODE END 2 */

  /* Infinite loop */
  /* USER CODE BEGIN WHILE */
  while (1)
  {
		// ADC tasks
		ADTasks();
		
		if(HAL_GetTick() - OldTick100ms > 100)
		{
			OldTick100ms = HAL_GetTick();
	
			//HAL_GPIO_TogglePin(STLED0_GPIO_Port, STLED0_Pin);

			// Display refresh and show data
			ButtonTask();
			
			// Scan buttons
			ShowDisplayTask();
		}		

  /* USER CODE END WHILE */

  /* USER CODE BEGIN 3 */

  }
  /* USER CODE END 3 */

}

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


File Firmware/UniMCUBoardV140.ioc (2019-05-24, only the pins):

Mcu.UserName=STM32L082KZTx
PA10.Signal=I2C1_SDA
PA11.Signal=USB_DM
PA12.Signal=USB_DP
PA13.Signal=SYS_SWDIO
PA14.Signal=SYS_SWCLK
PA15.GPIO_Label=HIGH_RANGE
PA15.Signal=GPIO_Input
PA2.GPIO_Label=MC_TXD2
PA2.Signal=USART2_TX
PA3.GPIO_Label=MC_RXD2
PA3.Signal=USART2_RX
PA4.GPIO_Label=ADV
PA4.Signal=ADC_IN4
PA5.GPIO_Label=ROTB
PA5.Signal=GPXTI5
PA6.GPIO_Label=STLED0
PA6.Signal=GPIO_Output
PA7.GPIO_Label=ROTA
PA7.Signal=GPXTI7
PA8.GPIO_Label=ROTP
PA8.Signal=GPIO_Input
PA9.Signal=I2C1_SCL
PB0.GPIO_Label=ADL
PB0.Signal=ADC_IN8
PB1.GPIO_Label=ADH
PB1.Signal=ADC_IN9
PB3.Signal=SPI1_SCK
PB4.Signal=SPI1_MISO
PB5.Signal=SPI1_MOSI
PB6.GPIO_Label=MX_TXD1
PB6.Signal=USART1_TX
PB7.GPIO_Label=MC_RXD1
PB7.Signal=USART1_RX
PC14-OSC32_IN.GPIO_Label=FLASH_CS
PC14-OSC32_IN.Signal=GPIO_Output

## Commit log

2019-04-16 Initial commit. Version 1.4
    [mikroAmpMeterV140_AnalogFrontend.brd, mikroAmpMeterV140_AnalogFrontend.sch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]
2019-04-21 New version of Analog Frontend electronics V1.50. PCB design is finalised
    [mikroAmpMeterV140_AnalogFrontend.brd, mikroAmpMeterV140_AnalogFrontend.sch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]
2019-05-24 Added test firmare, device photos and some clean-up
    [mikroAmpMeterV140_AnalogFrontend.brd, mikroAmpMeterV140_AnalogFrontend.sch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]
2019-05-25 New firware version, added basic ADC measurements of Current and Voltage
2019-06-02 Implemented new Display screens for buger digits of existing measurements, implemented Average per period of time measurements and calculation, STLED0 now show Hi/Lo range
    [Testiranje.xlsx]

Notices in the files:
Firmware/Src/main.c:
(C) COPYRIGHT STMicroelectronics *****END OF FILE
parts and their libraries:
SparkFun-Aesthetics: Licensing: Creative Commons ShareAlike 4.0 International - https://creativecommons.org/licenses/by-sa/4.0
